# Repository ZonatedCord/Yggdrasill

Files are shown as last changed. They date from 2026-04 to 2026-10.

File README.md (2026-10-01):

<div align="center">

# Yggdrasill

**Smart LED plant pot** — custom ESP32 PCB, addressable LEDs, WLED firmware, a modular 3D-printed vase, and a native iOS app with Apple's Liquid Glass design.






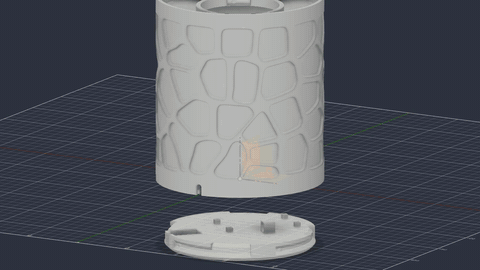
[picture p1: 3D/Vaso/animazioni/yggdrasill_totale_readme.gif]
Full assembly animation


</div>

---

## What it is

A tree-shaped plant pot built from three independent pieces that come together into one object:

<table>
<tr>
<td width="33%" valign="top">

### Hardware
`PCB/`

ESP32 board driving WS2812B / SK6812 addressable LEDs. 4 variants in KiCad, from a full dev-kit to a bare-chip revision.

</td>
<td width="33%" valign="top">

### 3D print
`3D/`

Modular vase — base, lid, trunk, 3 branches, leaves — joined with bayonet/snap-fit joints. FDM-printable in PETG or PLA.

</td>
<td width="33%" valign="top">

### iOS app
`WLED-iOS/`

Liquid Glass redesign (iOS 26) of a WLED controller. mDNS discovery, WebSocket control.

</td>
</tr>
</table>

---

## Assembly preview

<table>
<tr>
<td align="center" width="50%"><b>Leaf insertion</b></td>
<td align="center" width="50%"><b>Branch assembly</b></td>
</tr>
<tr>
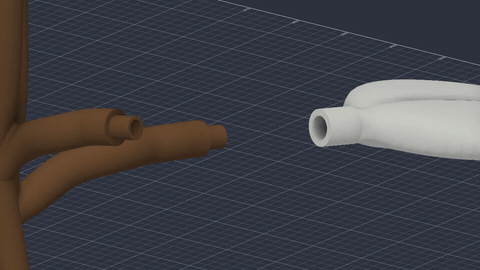
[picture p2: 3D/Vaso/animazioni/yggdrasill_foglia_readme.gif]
<td></td>
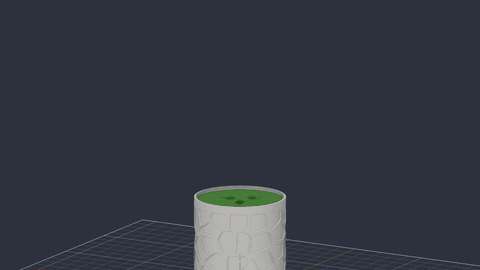
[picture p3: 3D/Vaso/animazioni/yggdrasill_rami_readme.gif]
<td></td>
</tr>
</table>

---

## Status

| Component | Status |
|---|---|
| BaseChipOnly PCB | **Recommended.** Rev 1.03 (`PCB/BaseChipOnly/`, fabricated) works with workarounds. **Rev 2.0** (`PCB/BaseChipOnly_rev2/`) fixes every bring-up defect, new layout — verified by DRC/ERC and simulation only, **not yet fabricated or tested on hardware** |
| BaseDevKit PCB | Active |
| BaseUSB-C rev0.1 PCB | Early revision |
| Foglia PCB | Active |
| Modular vase (`3D/STL_stampa/`) | Redesigned as modular parts — fit clearances and bayonet joints not yet verified by a physical print |
| iOS app (Liquid Glass) | In development |

---

## Quick start

### Hardware

Gerber files are in `PCB/<variant>/Esportazione/`. Upload to JLCPCB or PCBWay.
Open the KiCad project in **KiCad 8+** for schematic / PCB editing.
See [docs/hardware.md](docs/hardware.md) for the full variant table and BOM.

### 3D printing

Print-ready STLs are in `3D/STL_stampa/`. PETG recommended, 0.2 mm layers.
See [docs/3d-printing.md](docs/3d-printing.md) for orientation and joint-clearance notes.

### iOS app

Requires **Xcode 16+** and an **iOS 26+** device or simulator.

```bash
git clone --recurse-submodules https://github.com/ZonatedCord/Yggdrasill
open WLED-iOS/wled.xcodeproj
```

> `WLED-iOS/` is a git submodule pointing to the `liquid-glass-redesign` branch of [ZonatedCord/WLED-iOS](https://github.com/ZonatedCord/WLED-iOS) — a fork of [Moustachauve/WLED-iOS](https://github.com/Moustachauve/WLED-iOS) restyled with Apple's Liquid Glass (iOS 26). Already cloned without `--recurse-submodules`? Run `git submodule update --init`.

---

## Repository structure

```
Yggdrasill/
├── PCB/               KiCad projects — 4 board variants + footprint library
├── 3D/                Modular vase — Vaso/ (Fusion source + STEP + animations), STL_stampa/ (print-ready STLs)
├── WLED-iOS/          iOS app (Liquid Glass, GPL v3) — git submodule → ZonatedCord/WLED-iOS @ liquid-glass-redesign
├── docs/              Hardware, iOS, 3D, and assembly documentation
│   └── hardware-reviews/  PCB analysis notes
├── LICENSE            CC BY-NC-SA 4.0 (hardware + 3D)
├── LICENSE-NOTICES.md Dual-license clarification
├── CHANGELOG.md
└── CONTRIBUTING.md
```

---

## Documentation

- [Hardware variants & BOM](docs/hardware.md)
- [iOS app architecture & Liquid Glass](docs/ios-app.md)
- [3D printing guide](docs/3d-printing.md)
- [Assembly guide](docs/assembly.md)
- [BaseChipOnly — how the board works](docs/base-chiponly-pcb.md) · [Rev 2.0: tests and changes](PCB/BaseChipOnly_rev2/README.md)
- [BaseChipOnly hardware review](docs/hardware-reviews/base-chiponly-review.md) · [bring-up defects & fixes](docs/hardware-reviews/base-chiponly-fixes.md)

---

## License

**Hardware & 3D models** (`PCB/`, `3D/`, `docs/`) — Creative Commons Attribution-NonCommercial-ShareAlike 4.0 International, Copyright (c) 2025 Marco Barlera. Free for personal and maker use; commercial use requires explicit written permission.
See [LICENSE](LICENSE) · [creativecommons.org/licenses/by-nc-sa/4.0](https://creativecommons.org/licenses/by-nc-sa/4.0/)

**iOS app** (`WLED-iOS/`) — GNU General Public License v3.0, inherited from [Moustachauve/WLED-iOS](https://github.com/Moustachauve/WLED-iOS). Copyleft; cannot be changed.
See [WLED-iOS/LICENSE](WLED-iOS/LICENSE)

Full dual-license details: [LICENSE-NOTICES.md](LICENSE-NOTICES.md)

---

<div align="center">

**Marco Barlera** — [marcobarlera.com](https://marcobarlera.com) — barleramarco05@gmail.com

Commercial licensing inquiries: contact via email.

</div>

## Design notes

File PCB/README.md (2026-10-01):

# PCB — Hardware Variants

KiCad 8 projects. ESP32 + WS2812B/SK6812 addressable LEDs.

| Folder | Description | Status | Gerbers |
|---|---|---|---|
| `BaseDevKit/` | ESP32 dev kit carrier | Active | `BaseDevKit/Esportazione/` |
| `BaseChipOnly/` | Bare ESP32-WROOM-32, compact — rev 1.03 as fabricated | Superseded by the next rev | `BaseChipOnly/Esportazione/` |
| `BaseChipOnly_rev2/` | BaseChipOnly HW Rev 2.0: all bring-up fixes + new layout (see its `README.md`) | Verified on paper (DRC/ERC/simulation), not yet fabricated | `BaseChipOnly_rev2/Esportazione-2026-09-30/` |
| `BaseUSB-C_rev0.1/` | USB-C power input | Early rev | — |
| `Foglia/` | Leaf-shaped decorative board | Active | `Foglia/Esportazione/` |
| `Impronte/` | Custom KiCad footprint library | Library | — |

For fabrication details and BOM see [docs/hardware.md](../docs/hardware.md).

How BaseChipOnly works: [docs/base-chiponly-pcb.md](../docs/base-chiponly-pcb.md). For the design review see [docs/hardware-reviews/base-chiponly-review.md](../docs/hardware-reviews/base-chiponly-review.md).

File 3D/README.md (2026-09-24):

# 3D Models

FDM-printable parts for the Yggdrasill LED plant pot. The vase is now a **modular design** (base + lid + trunk/vase + 3 branches + leaves) with bayonet/snap-fit joints, replacing the earlier single-piece `VasoGiusto` body.

## Folder layout

- `3D/Vaso/` — Fusion 360 source of truth: STEP files (`Base.step`, `Coperchio.step`, `Vaso.step`, `Vaso_senza_texture.step`), the raw CAD-orientation STL exports, and `animazioni/` (assembly animation renders).
- `3D/STL_stampa/` — **print-ready** STLs, reoriented/optimized per part for the slicer. Use these for printing.

## Parts (`3D/STL_stampa/`)

| File | Description | Bed footprint (X×Y×Z mm) | Print notes |
|---|---|---|---|
| `Vaso.stl` | Trunk / vase body | 150×150×167 | Print **capovolto** (upside down) — cable slot must be on the print bed |
| `Base.stl` | Vase base — carries the PCB mounting points | 135×135×25 | Bayonet joint to lid — see clearances below. **Designed for `BaseChipOnly` only**, see PCB compatibility below |
| `Coperchio.stl` | Lid | 143×143×18 | Bayonet joint to base — see clearances below |
| `Ramo_1.stl` | Branch 1 | 101×129×324 | Too tall for upright printing on a 256 mm-Z printer (P2S) — must lie down or print at an angle |
| `Ramo_2.stl` | Branch 2 | 157×128×335 | Too tall for upright printing on a 256 mm-Z printer (P2S) — must lie down or print at an angle |
| `Ramo_3.stl` | Branch 3 | 99×153×324 | Too tall for upright printing on a 256 mm-Z printer (P2S) — must lie down or print at an angle |
| `Foglia.stl` | Decorative leaf, pairs with `PCB/Foglia/` | 83×27×135 | Some already printed — need **9 total** |

### Important print details

- **Rough/textured skin** on the branches applies **only** to the branch bodies — it must be **excluded** from the tenons ("codoli") and the square mounting boss ("cubotto"), or the joints won't fit.
- Fit clearances are simulated but **not yet verified empirically**: 0.2 mm/side on the bosses, 0.225 mm on the base. **Print small bayonet test rings for base + lid first**, before committing filament to the full-size parts — the snap-fit has only been checked in simulation.
- If a branch doesn't fit the print bed/angle in your slicer, a hidden joint/graft can be added to shorten it for printing in two pieces — re-export from Fusion if so.

## PCB compatibility

These files (`Base.stl`'s PCB mounting points, and `TasselloFissaggioPCB.stl`) are designed for the **`BaseChipOnly`** PCB variant only (see [PCB/BaseChipOnly](../PCB/BaseChipOnly)). Using `BaseDevKit` or `BaseUSB-C` instead requires redesigning the base's mounting points in Fusion to match that board's outline/holes before printing.

## Assembly animations

Lightweight renders for the README live in `3D/Vaso/animazioni/`:
- `yggdrasill_foglia_readme.gif` — leaf insertion
- `yggdrasill_rami_readme.gif` — branch assembly
- `yggdrasill_totale_readme.gif` — full assembly

Full-quality versions (`*.mp4`/non-`_readme` `.gif`) are also kept in the same folder for reference/editing.

For print settings and assembly notes see [docs/3d-printing.md](../docs/3d-printing.md).

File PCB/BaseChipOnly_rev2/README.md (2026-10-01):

# BaseChipOnly — HW Rev 2.0

Base board of the Yggdrasill lamp: ESP32-WROOM-32U running WLED, 5 V input, drives the 9 leaf boards (`../Foglia`, 15 WS2812B each, wired in parallel). This is the second revision of `../BaseChipOnly` (rev 1.03, the board that was actually fabricated and brought up).

How the board works, power budget and WLED settings: [`docs/base-chiponly-pcb.md`](../../docs/base-chiponly-pcb.md).

> ## ⚠️ Limitation: verified on paper, not on a real board
>
> Rev 2.0 has **not been fabricated or assembled yet**. Everything below was checked with design-rule tools, file cross-checks and circuit simulation — nothing has been measured on hardware. Simulations use component models (TI's LM2596 model, generic MMBT3904/SS34/LED models) and assumptions (cable resistance, wire length to the leaves, capacitor derating) that may differ from reality. The firmware/boot of the ESP32 cannot be simulated: "it boots" means EN and IO0 reach the right levels at the right time.
>
> Before trusting it, build one board and follow the **first power-up procedure** in `docs/base-chiponly-pcb.md`, then test the auto-reset with `esptool.py flash_id`.

## Status

| | |
|---|---|
| Schematic | complete, ERC 0 errors |
| PCB | complete, DRC 0 errors, schematic ↔ PCB parity clean |
| Fab files | `Esportazione-2026-09-30/` (Gerbers, drill, BOM with MPNs, pick-and-place, assembly PDF with values, schematic PDF, 3D preview) |
| Fabricated | **no** |
| Tested on hardware | **no** |

## Tests performed (all theoretical)

| Test | Tool | Result |
|---|---|---|
| Electrical rules check | KiCad ERC | 0 errors |
| Design rules check + schematic parity | KiCad DRC `--schematic-parity` | 0 errors, 0 unconnected, 0 parity issues (12 known items: 0.2 mm thermal-via drills of the ESP32 footprint, same as rev 1.03) |
| Copper vs schematic | Gerber X2 pad attributes of the exported front copper | 120 / 120 pads on the right net |
| Pinout of every active part vs datasheet | netlist + datasheets | 0 mismatches (LM2596S-ADJ, USBLC6-2SC6, MMBT3904, diodes, polarised caps, connectors, ESP32) |
| ESP32 strapping pins | netlist review | IO0 pull-up + BOOT; IO2/IO12 floating (download mode OK, 3.3 V flash); IO5/IO15 internal pull-ups |
| Trace current capacity | IPC-2221, 1 oz outer layer, +10 °C | all power traces above their current (e.g. +5V bus 3 mm → 5.3 A for ~3.3 A) |
| Fab limits | JLCPCB rules | tracks ≥ 0.2 mm, vias 0.6/0.3, copper ≥ 1 mm from edge, silkscreen ≥ 0.8 mm / 0.15 mm |
| Mechanical / visual | KiCad 3D render | polarity marks, orientation, ≥ ~1 mm between parts in the regulator block, ≥ 1.1 mm from the ESP32 |
| Auto-reset (both esptool sequences) | ngspice | enters download mode; serial monitor does not reset the board |
| Power-on EN timing | ngspice | EN rises 13.7 ms after 3.3 V (spec ≥ 50 µs) |
| 3.3 V regulator: nominal, LEDs at 3 A, minimum input, start-up | ngspice + Texas Instruments LM2596 model (SNVMA65, credited in `LICENSE-NOTICES.md`) | 3.28 V, ≥ 3.21 V worst case; needs ≥ ~4.5 V at its input |
| Status LED current | ngspice | 4.6–6.7 mA |
| LED data line to 9 parallel leaves | ngspice | clean ~370/770 ns pulses with R5 = 100 Ω |

Re-run the checks with `./verifica.sh` (ERC + DRC/parity + fab export + Gerber cross-check). Simulations: `simulazioni/README.md` (run `simulazioni/models/get_lm2596_model.sh` once to fetch the TI model).

## Changes from rev 1.03

**Bugs fixed (all seen during the rev 1.03 bring-up)**

| Rev 1.03 | Rev 2.0 |
|---|---|
| D2 (SS34 catch diode) reversed — shorts the regulator switch node | correct polarity, silkscreen matches |
| D1 (status LED) reversed | correct polarity; GND via moved out of the pad (likely cause of the dark LED) |
| Auto-reset wired wrong: both emitters to GND — idle adapter held the ESP32 in reset, esptool could never enter download mode | standard cross-coupled DTR/RTS circuit, like ESP32 DevKit boards |
| No BOOT / RESET buttons | SW1 BOOT, SW2 RESET (C&K PTS810), centred on the top edge |
| L1 1008 inductor, no value — burned out | Bourns SRN6045TA-101M, 100 µH, Isat 1.33 A |
| Polyfuse 12 A in 0603 — protects nothing | Bourns MF-LSMF400/12X, 4 A hold, 2920 |
| U3 (USBLC6) GND pin unconnected — no ESD protection | GND connected, VBUS to +5V (ST reference circuit) |
| TVS: bidirectional symbol, SMF5.0A part on an SMA footprint | SMAJ5.0A, unidirectional, matches the footprint |
| Reference and Value swapped on the PCB, footprints not linked to the schematic | fixed: correct BOM / pick-and-place, Update-PCB-from-Schematic works |
| 12 ESP32 thermal vias with no net | tied to GND |
| Silkscreen typo "GDN" | "GND" |

**Improvements**

- COUT2 220 µF tantalum (Kyocera AVX TPSC227M006R0100) next to the 47 µF MLCC, for LM2596 loop stability.
- C4 100 nF → 1 µF (EN delay, Espressif guideline) — from the simulations.
- R5 470 Ω → 100 Ω (clean data pulses to the 9 parallel leaves) — from the simulations.
- Auto-reset transistors specified as MMBT3904 (no part number before).
- +3V3 traces 0.2 → 0.5–1.0 mm; SW node 1.2–1.5 mm.
- New layout: functional blocks, regulator with a short switching loop and room for hand soldering, solid GND plane on the back, no via-in-pad on GND, silkscreen to fab minimums, HW Rev 2.0 printed on the board.

**Unchanged on purpose:** board outline and mounting holes (the printed base and `TasselloFissaggioPCB.stl` still fit), J1 barrel jack, J2 terminal, J3 programming header (external USB-UART adapter, no USB-C), ESP32 position, C1, LED data on GPIO13.

## Known limits

- The LM2596 needs ≥ ~4.5 V at its input at 500 mA: use a good 5 V 4 A PSU with a short, thick cable and keep the WLED current limiter at 3000 mA.
- The USB-UART adapter must break out **DTR and RTS** at 3.3 V for the auto-reset; otherwise use BOOT/RESET.
- Button reachability inside the printed base not checked.

## Folder contents

| Path | What |
|---|---|
| `BaseChipOnly.kicad_pro/.kicad_sch/.kicad_pcb` | KiCad 9 project |
| `Esportazione-2026-09-30/` | fabrication files for rev 2.0 |
| `verifica.sh` | all automatic checks in one go |
| `simulazioni/` | ngspice decks, plots, results |
| `FIX_LOG.md` | session-by-session log of every change (Italian) |
| `BaseChipOnly-backups/fixpcb_2026-09-30.py`, `relayout-work/relayout.py`, `build.sh` | scripts that generated the PCB (record of every edit; their input boards live in the local, git-ignored `BaseChipOnly-backups/`) |
| `FileImpronte/` | ESP32-WROOM-32U symbol / footprint / 3D model |

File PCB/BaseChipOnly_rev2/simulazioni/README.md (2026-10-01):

# BaseChipOnly — circuit simulations (2026-09-30)

SPICE simulations of every analog block of the base board, run with **ngspice 47** (`brew install ngspice`) in PSpice-compatibility mode (`.spiceinit`). Component values and nets are taken from `../BaseChipOnly.kicad_sch`.

What a SPICE simulation can and cannot tell you: it checks voltages, currents and timing of the circuit around the ESP32. It does **not** run the ESP32 firmware — "does the chip boot" is answered by checking that EN and IO0 reach the right levels at the right time, which is exactly what the ESP32 needs to boot or enter download mode.

## Results

| # | Block | Result | Verdict |
|---|---|---|---|
| 01 | **Auto-reset** (esptool UnixTight + Classic sequences) | EN pulled to 0.07 V during reset; when EN is released, IO0 is at 0.07 V and stays low for 36–48 ms after EN crosses 2.475 V → **download mode**. Serial monitor opening with DTR=RTS=1 → no reset. | ✅ works |
| 01b | Auto-reset **as fabricated (rev 1.03)** | Idle adapter holds EN at 0.04 V (chip stuck in reset); the esptool sequence never pulls EN low. Explains the bring-up ("disconnect DTR/RTS or it won't work"). | ❌ confirmed broken |
| 01c | Auto-reset with **C4 = 1 µF** | Same as 01, EN crosses the threshold 13.7 ms after release, IO0 still low for another 36 ms. | ✅ works |
| 02 | **LM2596 buck**, nominal 5 V in, ESP32 load 60/250/500 mA | +3V3 = **3.280 V**, ripple 0.8 mV p-p, minimum 3.263 V during 500 mA TX bursts, L1 peak 0.6 A in steady state. | ✅ |
| 02b | Buck, **LEDs drawing 3 A** from +5V (WLED limiter) + real switch saturation + 500 mA TX | +5V sags to 4.51 V (0.15 Ω cable+jack+fuse), +3V3 stays 3.28 V, **minimum 3.21 V** during TX. | ✅ small margin |
| 02c | Buck **minimum input voltage** at 500 mA | Regulates down to **~4.5 V** in; 4.3 V in → 3.11 V out; below ~4.2 V the ESP32 minimum (3.0 V) is lost. | ⚠️ see note |
| 02d | Buck start-up with a real adapter (5 V in 10 ms) | L1 peak **0.86 A** (< Isat 1.33 A), +3V3 in 6.9 ms, overshoot 3.43 V (< 3.6 V max). With a 1 ms edge (hot-plugging into a live PSU) L1 briefly reaches ~3 A, limited by the LM2596 current limit. | ✅ |
| 03 | **Power-on**, EN delay vs +3V3 (C4 100 nF) | EN crosses 2.475 V 1.05 ms after +3V3 is up (adapter unplugged). With the adapter connected and idle, EN is back-fed to 1.7 V before power and rises only **65 µs** after +3V3 (spec ≥ 50 µs). | ⚠️ marginal |
| 03b | Power-on with **C4 = 1 µF** | EN 13.7 ms after +3V3 (3.3 ms with the adapter connected). IO0 high → normal boot. | ✅ |
| 04 | **Status LED** D1 (R0 470 Ω from 5 V) | 6.7 mA (red) / 4.6 mA (white/blue). Not too much current; D1 being dark on the rev 1.03 board is not an electrical-design problem. | ✅ |
| 05 | **LED data line** to 9 leaves in parallel | With R5 = 470 Ω the pulses seen at a leaf (2.5 V threshold) shrink: 0.3 m wires → "0" ≈ 265 ns, "1" ≈ 670 ns; 0.6 m → "0" ≈ 190 ns, "1" ≈ 600 ns (WS2812B limits: T0H ≥ 220 ns, T1H ≥ 580 ns). With **R5 = 100 Ω**: "0" 350–370 ns, "1" 750–770 ns, no ringing. | ⚠️ → fixed with 100 Ω |

## Changes made because of these results

- **C4 100 nF → 1 µF** (EN RC = 10 kΩ + 1 µF, Espressif hardware design guidelines). Removes the 65 µs power-on margin; auto-reset re-verified (01c).
- **R5 470 Ω → 100 Ω** (LED data series resistor). Restores full-width pulses at the leaves.
- **IO0_CTRL1 / EN_CTRL1 = MMBT3904** — the transistors had no part number at all.

Same footprints: only values change, the layout is untouched.

## Note on the LM2596 at 5 V input (02c)

The LM2596 switch is a Darlington with ~1 V saturation, so with 5 V in it needs **≥ ~4.5 V at its VIN pin** to hold 3.3 V at 500 mA. Everything between the PSU and U4 eats into that: PSU tolerance, cable, barrel jack, polyfuse. With the LEDs at 3 A and 0.15 Ω of path resistance it still works (02b), but a long thin cable or a sagging PSU would drop the ESP32 into brown-out. Practical rules:

- use a decent 5 V 4 A supply (a 5.1–5.2 V one is even better) with a short, thick cable;
- keep the WLED current limiter on (3000 mA).

For a future revision, a 1 A LDO (e.g. AP7361C-33, ~0.36 V dropout) would be a better fit than a buck at 5 V → 3.3 V: at ~250 mA average the LDO dissipates < 0.5 W.

## Files

| File | What |
|---|---|
| `01_autoreset.cir`, `01b_…rev103.cir`, `01c_…C4_1u.cir` | auto-reset (new circuit / as fabricated / C4 1 µF) |
| `02_buck_nominal.cir`, `02b_…ledload_vsat.cir`, `02c_…dropout.cir`, `02d_…slowramp.cir` | LM2596 buck (share `buck_common.inc`) |
| `03_poweron.cir`, `03b_poweron_C4_1u.cir` | power-on EN delay (uses `v33.inc` = +3V3 start-up from 02) |
| `04_status_led.cir` | status LED current |
| `05_dataline.cir` | LED data line to 9 leaves |
| `models/get_lm2596_model.sh` | downloads TI's LM2596_3P3 unencrypted transient model (SNVMA65) and derives `models/LM2596_ADJ.lib` (internal divider removed → ADJ version; `LM2596_ADJ_VSAT` adds the datasheet switch saturation). The TI file itself is not stored in the repo |
| `models/transistors.lib` | MMBT3904, SS34, LED models |
| `grafici/*.png` | plots (from `plot.py`) |

## Credits

The LM2596 regulator simulations use Texas Instruments' **LM2596_3P3 Unencrypted PSpice Transient Model** (SNVMA65, © 2015 Texas Instruments Incorporated, [ti.com/product/LM2596](https://www.ti.com/product/LM2596)). The model is not stored in this repository; `models/get_lm2596_model.sh` downloads it from TI and turns it into the adjustable version (internal divider removed, optional switch-saturation drop added). See also `LICENSE-NOTICES.md`.

## Re-run

```sh
cd "PCB/BaseChipOnly_rev2/simulazioni"
models/get_lm2596_model.sh                    # once: downloads TI's model and builds models/LM2596_ADJ.lib
for f in 0*.cir; do ngspice -b "$f"; done     # buck decks take ~4-5 min each
python3 plot.py                               # needs matplotlib + numpy
```

Assumptions worth knowing: COUT1 (47 µF 0805 X5R) derated to 20 µF at 3.3 V bias; 0.15 Ω from PSU to the +5V rail; leaf wires 0.3/0.6 m at ~50 pF/m, WS2812B input ~10 pF; USB-UART adapter outputs 3.3 V with 50 Ω.

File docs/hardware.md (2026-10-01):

# Hardware — PCB Variants

All boards are designed in **KiCad 8**. ESP32 + addressable LEDs (WS2812B / SK6812).

---

## Variants

| Folder | Description | Power | Status | Gerbers |
|---|---|---|---|---|
| `BaseDevKit` | ESP32 dev kit carrier board | 5V barrel/USB | Active | `BaseDevKit/Esportazione/` |
| `BaseChipOnly` | Compact bare ESP32-WROOM-32 | 5V | Rev 1.03 fabricated | `BaseChipOnly/Esportazione/` |
| `BaseChipOnly_rev2` | BaseChipOnly HW Rev 2.0: all fixes + new layout | 5V | Verified on paper only, not yet fabricated | `BaseChipOnly_rev2/Esportazione-2026-09-30/` |
| `BaseUSB-C_rev0.1` | USB-C powered, rev 0.1 | 5V USB-C | Early rev | — |
| `Foglia` | Leaf-shaped decorative board | 5V | Active | `Foglia/Esportazione/` |
| `Impronte` | Custom KiCad footprint library | — | Library | — |

**Recommended for new builds:** `BaseChipOnly` HW Rev 2.0 in `PCB/BaseChipOnly_rev2/` (see its [README](../PCB/BaseChipOnly_rev2/README.md) for the tests done and the not-yet-tested-on-hardware caveat) (all bring-up fixes, BOOT/RESET buttons, working auto-reset). How it works, power budget and WLED settings: [base-chiponly-pcb.md](base-chiponly-pcb.md).

---

## BOM (generic)

| Component | Description | Notes |
|---|---|---|
| ESP32-WROOM-32 | Main microcontroller | WLED firmware |
| WS2812B / SK6812 | Addressable RGB LEDs | SK6812 supports RGBW |
| AMS1117-3.3 or LDO | 3.3V regulator | Per schematic (BaseChipOnly uses an LM2596-ADJ buck) |
| 100nF + 47µF decoupling caps | Power filtering | See schematic |
| USB-C connector | Power input (BaseUSB-C only) | GCT USB4135 or similar |

For detailed BOM per variant, open the KiCad schematic.

---

## Fabrication notes

- **Layer count:** 2 layers
- **Min trace:** 0.2 mm
- **Min drill:** 0.3 mm
- **Surface finish:** HASL or ENIG
- **Thickness:** 1.6 mm

Upload the `Esportazione/` folder contents (or zip) to JLCPCB / PCBWay directly.

---

## Known issues

- `BaseChipOnly` as fabricated: D1 and D2 reversed, auto-reset non-functional, no BOOT/RESET buttons, undersized L1. All fixed in the sources in `PCB/BaseChipOnly_rev2/` (2026-09-30), not yet re-fabricated — see `docs/hardware-reviews/base-chiponly-fixes.md`. The older "via-on-pad short circuit" finding was false; see `docs/hardware-reviews/base-chiponly-review.md`.

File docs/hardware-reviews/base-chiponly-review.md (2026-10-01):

# Design Review — BaseChipOnly

Original review: 2026-03-28 (automated). **Rewritten 2026-09-30** after the bring-up proved its main finding false.

---

## Retraction: the "via-on-pad short circuits" do not exist

The 2026-03-28 version of this document named vias on C2, C3, COUT1, Rbot1 and Rtop1 as the "SHORT-CIRCUIT ROOT CAUSE", claiming each GND via had landed on the supply pad. **That is wrong.** Every one of those vias sits in its pad deliberately and carries the *same* net as the pad, to drop to the B.Cu ground plane.

Disproved two independent ways during the 2026-07/08 bring-up:

- The bare board measures no short between any rail and GND.
- The X2 attributes in the fabricated `F_Cu.gbr` (`%TO.P,comp,pin%` / `%TO.N,net%`) show pad and via on the same net at every flagged location — e.g. `COUT1 pin 2 net=GND`, and the via there is also `GND`.

The false finding came from hand-computing pad positions with the wrong rotation sign, which mirrors every pad about its footprint centre and pairs each via with the opposite pad. The error was self-consistent, which is why it looked convincing. Lesson: never derive pad-to-net mapping from footprint rotation math — read it from Gerber X2 attributes or `kicad-cli`.

The short that actually happened on the first assembled board was a **solder bridge between ESP32 module pins 1 (GND) and 2 (3V3)** — an assembly defect, not a design one. See `base-chiponly-fixes.md`.

---

## Findings that were valid, and their status

All of the following are fixed in the KiCad sources in `PCB/BaseChipOnly_rev2/` (2026-09-30). Full log: `PCB/BaseChipOnly_rev2/FIX_LOG.md`.

| Finding | Status |
|---|---|
| U3 (USBLC6-2SC6) GND pin unconnected | Fixed — pin 2 on GND. VBUS (pin 5) now on +5V as well, so the clamp has its rail reference. |
| Polyfuse 12 A protects nothing | Fixed — 4 A hold / 8 A trip, Bourns MF-LSMF400/12X, 2920, sized for the 9 leaves (135 WS2812B) with a 5 V 4 A PSU and the WLED current limiter at 3000 mA. The old 0603 footprint could not hold any realistic PTC. |
| +3V3 traces 0.2 mm | Fixed — +3V3 tracks widened to 0.5 mm. |
| Reference/Value swapped in the PCB | Fixed — Reference on F.Silkscreen, Value on F.Fab. Footprints are linked to their schematic symbols again, so BOM, pick-and-place and Update-PCB-from-Schematic work. |
| SMF5.0A on a bidirectional TVS symbol | Fixed — replaced with SMAJ5.0A (unidirectional, SMA package). SMF5.0A is an SOD-123F part and never matched the D_SMA footprint anyway. |

The Vout note in the old review used Vref = 1.285 V. The LM2596-ADJ reference is **1.23 V**, so Rtop = 2.0 k / Rbot = 1.2 k gives ≈ 3.28 V. No change needed.

---

## Defects found later (bring-up), also fixed

See `base-chiponly-fixes.md` for evidence. Fixed in the sources on 2026-09-30:

- D2 (SS34 catch diode) reversed
- D1 (status LED) reversed
- Auto-reset transistors wired with both emitters to GND — now the standard cross-coupled DTR/RTS circuit
- No BOOT/RESET buttons — SW1 (BOOT, IO0→GND) and SW2 (RESET, EN→GND) added
- L1 1008 inductor unable to carry the current — now Bourns SRN6045TA-101M (100 µH, Isat 1.33 A)
- COUT1 47 µF MLCC alone on the LM2596 output — COUT2 220 µF tantalum added

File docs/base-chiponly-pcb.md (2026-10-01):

# BaseChipOnly — how the board works

Base board of the Yggdrasill lamp: an ESP32-WROOM-32U running WLED drives the 9 leaf boards (`PCB/Foglia`). This describes **HW Rev 2.0**, sources in `PCB/BaseChipOnly_rev2/` — tests done, changes from rev 1.03 and the *not yet tested on hardware* caveat are in [its README](../PCB/BaseChipOnly_rev2/README.md).

## Block diagram

```
5V PSU ─► J1 barrel jack ─► Polyfuse1 ─► +5V bus ─┬─► J2 terminal (VIN/GND) ─► 9 leaves in parallel
                                                   ├─► C1 1000µF bulk, C2 100nF, D_TVS1 SMAJ5.0A (clamp)
                                                   ├─► R0 + D1  (power-on LED)
                                                   └─► U4 LM2596-ADJ buck ─► L1 100µH ─► +3V3 ─► ESP32 (U1)
ESP32 GPIO13 ─► R5 100Ω ─► U3 USBLC6 (ESD) ─► J2 "Data" ─► DIN of the first WS2812B on every leaf
J3 (GND 3V3 TX0 RX0 DTR RTS) ─► USB-UART adapter; DTR/RTS drive the auto-reset transistors
SW1 BOOT (IO0→GND), SW2 RESET (EN→GND)
```

## Blocks

**Power input.** J1 (GCT DCJ200-10, rated 5 A) → polyfuse → +5V. The +5V rail feeds the LEDs directly; only the ESP32 goes through the buck. D_TVS1 clamps spikes on +5V, C1 buffers the LED current steps.

**3.3 V regulator.** LM2596-ADJ, 150 kHz buck. Vout = 1.23 V × (1 + Rtop1/Rbot1) = 1.23 × (1 + 2.0k/1.2k) ≈ 3.28 V. D2 (SS34) is the catch diode (cathode on SW). L1 Bourns SRN6045TA-101M (Isat 1.33 A). COUT1 47 µF MLCC + COUT2 220 µF tantalum: the tantalum's ESR keeps the LM2596 loop stable. Simulated (TI model): 3.280 V, 0.8 mV ripple, ≥ 3.26 V during 500 mA WiFi bursts. With only 5 V in, the LM2596 runs close to dropout: it needs **≥ ~4.5 V at its input** to hold 3.3 V at 500 mA (its switch drops ~1 V) — see *Known limits*.

**ESP32.** U1 WROOM-32U (external antenna via U.FL). LED data is **GPIO13** = module pin 16 (set 13 in WLED, not 16).

**Programming / auto-reset.** J3 carries TX0/RX0/DTR/RTS. Two NPN transistors in the standard cross-coupled arrangement: DTR=1,RTS=0 → EN low (reset); DTR=0,RTS=1 → IO0 low (bootloader). esptool drives this sequence automatically. R3/R4 pull IO0/EN up; C4 (1 µF, with R4 = the 10 kΩ + 1 µF recommended by Espressif) delays EN at power-on. Verified by simulation for both esptool reset sequences: EN goes to 0.07 V, IO0 is still low when EN comes back up → download mode; opening a serial monitor does not reset the board. BOOT/RESET buttons are the manual fallback (hold BOOT, tap RESET).

**LED data.** R5 (100 Ω) damps ringing on the long wires to the leaves — it was 470 Ω, but with 9 leaves in parallel that RC shrank the WS2812B pulses close to their minimum width (simulated); 100 Ω delivers clean ~370/770 ns pulses; U3 protects the ESP32 pin from ESD coming back up the leaf wiring.

**Status LED.** D1 via R0 470 Ω from +5V → 6.7 mA for a red LED, 4.6 mA for white/blue (simulated). That is **not** too much current (0805 LEDs take 20 mA). D1 stays dark on the first assembled board for a reason still undiagnosed: check that R0 is fitted and reads 470 Ω, then measure the LED-anode pad against GND with the board on (≈5 V = no current; ≈2–3 V = current flowing, LED faulty). On the old layout the LED's GND pad has a via in the middle of the pad that sucks solder into the ground plane — a dry joint there is a likely cause. The new files move every GND via beside its pad.

## The leaves (PCB/Foglia) and the power budget

Each leaf: 15 × WS2812B daisy-chained, 100 nF per LED, 3-pad connector (+5V, Data, GND). The last LED's DOUT is not brought out, so the **9 leaves are wired in parallel** on the same data line: WLED is configured for 15 LEDs and all leaves show the same pattern.

| | |
|---|---|
| LEDs | 9 × 15 = 135 WS2812B |
| Worst case (full white, ~55 mA/LED) | ≈ 7.4 A |
| ESP32 (from +5V, via the buck) | ≈ 0.3 A peak |
| Barrel jack limit | 5 A |

So full white at full brightness is **not possible** on this hardware — WLED's current limiter must be on:

- **PSU: 5 V 4 A** (20 W) recommended
- **WLED → LED preferences → Automatic Brightness Limiter: max current 3000 mA**, LED current 55 mA (5 V WS2812)
- Polyfuse MF-LSMF400/12X (4 A hold, 8 A trip, 2920) — above the 3 A limiter plus ESP32, below the fault currents

If you use a smaller PSU, lower the WLED limit to about 80 % of its rating.

## Layout (re-done 2026-09-30, spaced out 2026-10-01)

Board outline, the four mounting holes, J1, J2, J3, U1 and C1 are where they always were, so the printed base and the PCB mount (`TasselloFissaggioPCB.stl`) still fit. Everything else was re-placed in functional blocks:

- **Left column — 3.3 V buck.** U4 with its pins pointing up; directly above the pins D2 (catch diode), L1 and the output caps COUT1/COUT2/C3, so the switching loop U4 OUT → D2 → GND is a few millimetres long. Rtop1/Rbot1 sit next to the FB pin. CIN1/C2 are right at the VIN pin. The block keeps ~1 mm between parts so it can be hand-soldered with an iron.
- **Bottom left — input.** Jack → polyfuse (2920) → a 3 mm +5V bus that runs across the board to C1 and up to the regulator, with a 2 mm branch to J2. The TVS sits on the bus next to the polyfuse.
- **Bottom right — power LED** (R0 + D1) next to C1, fed by a thin branch of the +5V bus.
- **Under the ESP32 — auto-reset.** R1–R4, C4, the two transistors, then R5/U3 feeding J2 "Data".
- **Top edge — RESET and BOOT buttons**, centred on the board, with RESET/BOOT printed on either side.
- **Back — solid GND plane.** Only a few short signal jumpers cross it (DTR/RTS lanes from J3, EN and IO0 under the module, IO13). Every GND pad has its via beside the pad, not in it (easier hand soldering, no solder wicking — see the D1 note above).
- The credit text stays on the front, right edge; the logo stays on the back.

Rebuild recipe (deterministic, all routing by hand): `PCB/BaseChipOnly_rev2/BaseChipOnly-backups/relayout-work/relayout.py` + `build.sh`.

## Simulations

Every analog block was simulated in ngspice (TI's LM2596 model, MMBT3904 transistors): auto-reset, power-on EN timing, the 3.3 V buck (nominal, LEDs at 3 A, minimum input voltage, start-up), status LED, LED data line. Results, plots and decks: `PCB/BaseChipOnly_rev2/simulazioni/README.md`. Three values changed because of them: **C4 100 nF → 1 µF**, **R5 470 Ω → 100 Ω**, transistors specified as **MMBT3904**.

## Pre-order checks (2026-09-30)

Run `PCB/BaseChipOnly_rev2/verifica.sh` after any change: ERC, DRC with schematic parity, regenerates the fab files and cross-checks every pad of the exported front-copper Gerber against the schematic. Last run: **PASS** (0 ERC errors, 0 DRC errors, 0 unconnected, 0 parity issues, 120/120 pads match).

Also checked by hand:

- **Pinouts** of every active part against its datasheet: LM2596S-ADJ (1 VIN, 2 OUT, 3 GND, 4 FB, 5 ON/OFF), USBLC6-2SC6, MMBT3904 SOT-23 (1 B, 2 E, 3 C), SS34/SMAJ5.0A/LED (pad 1 = cathode), tantalum and C1 (pad 1 = +), J2/J3 order, ESP32 power/EN/IO0/IO13/UART pins.
- **ESP32 strapping pins:** IO0 pulled up + BOOT button; IO2 and IO12 floating (download mode allowed, flash at 3.3 V); IO5/IO15 floating (internal pull-ups).
- **Trace current (IPC-2221, 1 oz outer, +10 °C):** +5V bus 3.0 mm → 5.3 A; J2 branch and jack input 2.0 mm → 4.0 A; SW node ≥ 1.2 mm → 2.7 A; +3V3 ≥ 0.6 mm → 1.7 A. LED current returns through the solid GND plane.
- **Fab limits (JLCPCB):** min track 0.2 mm, vias 0.6/0.3 mm, copper ≥ 1.07 mm from the edge, silkscreen ≥ 0.8 mm / 0.15 mm line. The 12 ESP32 thermal vias are 0.2 mm (same as the rev 1.03 order).
- **3D view:** diode bands, tantalum +, regulator orientation, button access (`Esportazione-2026-09-30/preview-3d-top.png`).
- **Every part has an MPN** except generic resistors/capacitors (value + size is enough).

Not verifiable from the files: the fit of the new buttons in the printed base (they sit on the top edge next to J3), and the USB-UART adapter (must break out DTR **and** RTS at 3.3 V).

## First power-up (recommended)

1. Before soldering the ESP32 module: fit the power section only (J1, polyfuse, TVS, C1/C2/CIN1, U4, D2, L1, COUT1/COUT2/C3, Rtop1/Rbot1).
2. Measure +5V↔GND and +3V3↔GND with the multimeter: anything under ~100 Ω means a solder bridge.
3. Power it (bench supply limited to ~300 mA if available): +3V3 must read 3.25–3.30 V.
4. Fit the ESP32, the auto-reset parts and the buttons; repeat step 2 on +3V3 (the rev 1.03 short was a bridge between module pins 1 and 2).
5. Connect the adapter (3.3 V, GND/TX/RX/DTR/RTS; leave its 3V3 unconnected), flash WLED; the board should enter download mode by itself.

## Known limits

- The ESP32 drives 3.3 V data into WS2812B powered at 5 V (spec wants ≥3.5 V). It works in practice on this build; if leaves flicker, the fix is a 74AHCT1G125 buffer powered from +5V between GPIO13 and R5.
- **LM2596 input headroom.** The regulator needs ≥ ~4.5 V at its input at 500 mA. With the LEDs at the 3 A limit, the +5V rail sits at ~4.5 V (0.15 Ω of cable + jack + polyfuse) and the 3.3 V rail still holds (≥ 3.21 V) — but a long thin cable or a weak PSU would brown out the ESP32. Use a good 5 V 4 A supply (5.1–5.2 V is better) with a short thick cable, and keep the WLED limiter on. A future revision could use a 1 A LDO (e.g. AP7361C-33) instead of the buck.
- 12 DRC "drill 0.2 mm" items: thermal vias of the ESP32 footprint, same as the board already made.

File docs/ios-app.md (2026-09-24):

# iOS App — WLED Native

A native iPhone/iPad app to discover and control WLED devices on the local network.

---

## Overview

Yggdrasill's iOS app is a fork of [Moustachauve/WLED-iOS](https://github.com/Moustachauve/WLED-iOS) (GPL v3), restyled with **Apple's Liquid Glass** design language (iOS 26). Published fork: [ZonatedCord/WLED-iOS](https://github.com/ZonatedCord/WLED-iOS) (`origin`; `upstream` = Moustachauve/WLED-iOS). Embedded here as a **git submodule** tracking the `liquid-glass-redesign` branch — clone Yggdrasill with `--recurse-submodules` to pull it in.

The app communicates with WLED firmware running on the ESP32 via:
- **WebSocket** — real-time state sync
- **WLED JSON API** — device discovery and control
- **mDNS** — automatic device detection on LAN

---

## Architecture

```
WLED-iOS/
├── wled/
│   ├── Model/          # Data models (Device, LEDState, Palette, …)
│   ├── ViewModel/      # ObservableObjects for SwiftUI bindings
│   ├── View/           # SwiftUI views — Liquid Glass redesign here
│   ├── Service/        # Network layer (WebSocket, HTTP, mDNS)
│   └── WLEDNativeApp.swift   # App entry point
├── Data/               # CoreData schema (wled_native_data.xcdatamodeld)
└── wled.xcodeproj
```

Pattern: **MVVM**. Models in `Model/`, view models in `ViewModel/`, views in `View/`.

---

## Liquid Glass redesign

The fork replaces the original flat UI with Apple's **Liquid Glass** material system (introduced iOS 26):

- Device list cards use `.glassEffect()` with specular highlights
- Controls use glass-backed sliders and toggles
- Color picker adopts radial blur behind glass panels
- Light/dark mode: glass adapts automatically to ambient lightness
- Requires **iOS 26+** deployment target (verify in `Info.plist`)

---

## Build

1. Open `WLED-iOS/wled.xcodeproj` in **Xcode 16+**
2. Set a valid development team in Signing & Capabilities
3. Build to a physical device or simulator (iOS 26+)

---

## Dependencies

No external package managers. Pure Swift / SwiftUI + CoreData.

---

## License

GPL v3 — inherited from upstream. See `WLED-iOS/LICENSE`. Cannot be changed.

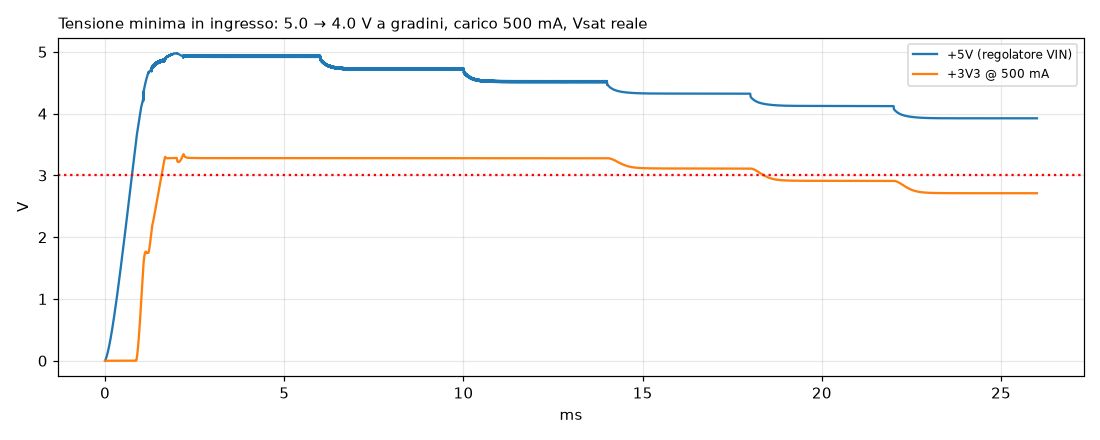
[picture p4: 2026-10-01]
PCB/BaseChipOnly_rev2/simulazioni/grafici/02c_buck_dropout.png

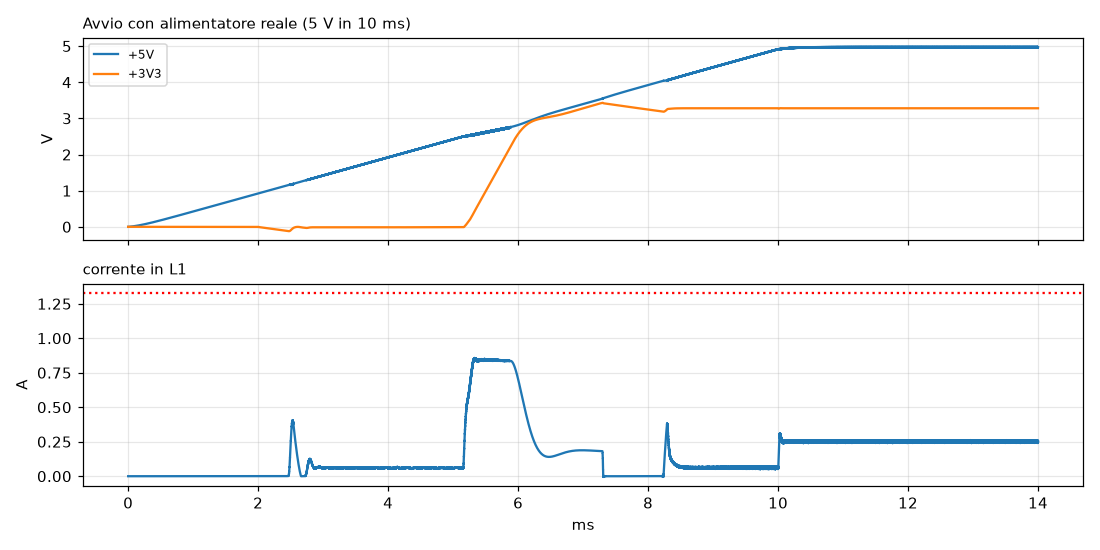
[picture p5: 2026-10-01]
PCB/BaseChipOnly_rev2/simulazioni/grafici/02d_buck_slowramp.png

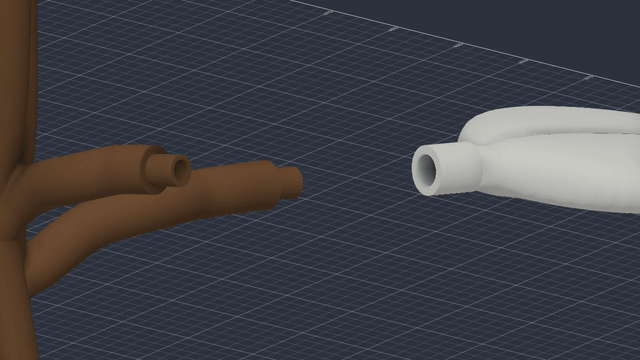
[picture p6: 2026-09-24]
3D/Vaso/animazioni/yggdrasill_foglia.gif

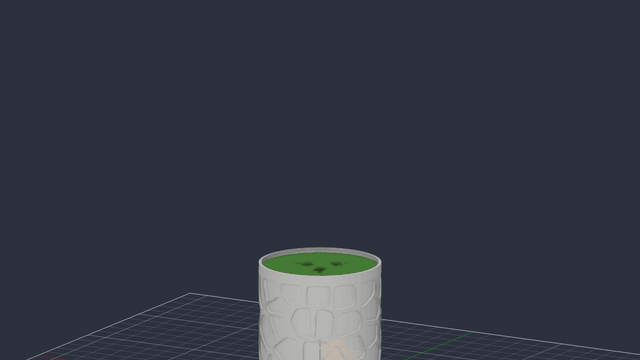
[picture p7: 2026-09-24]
3D/Vaso/animazioni/yggdrasill_rami.gif

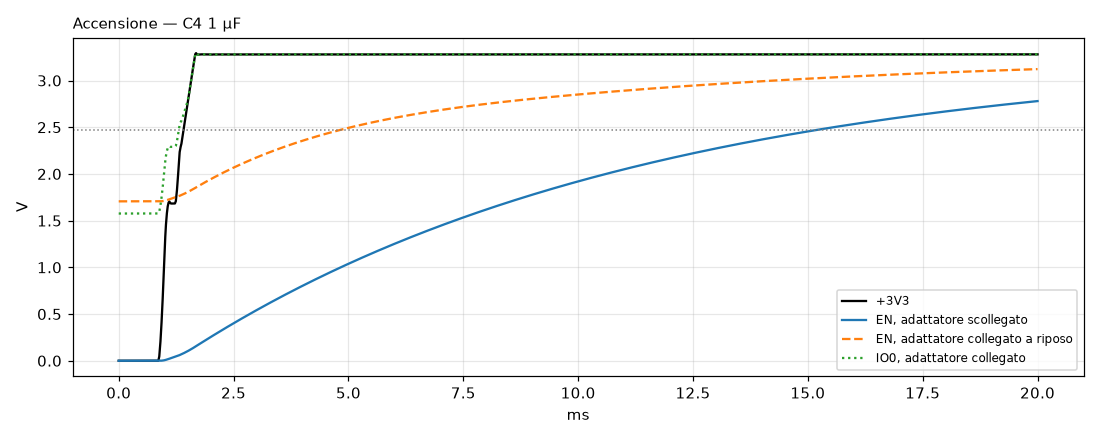
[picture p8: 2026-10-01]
PCB/BaseChipOnly_rev2/simulazioni/grafici/03b_poweron_C4_1u.png

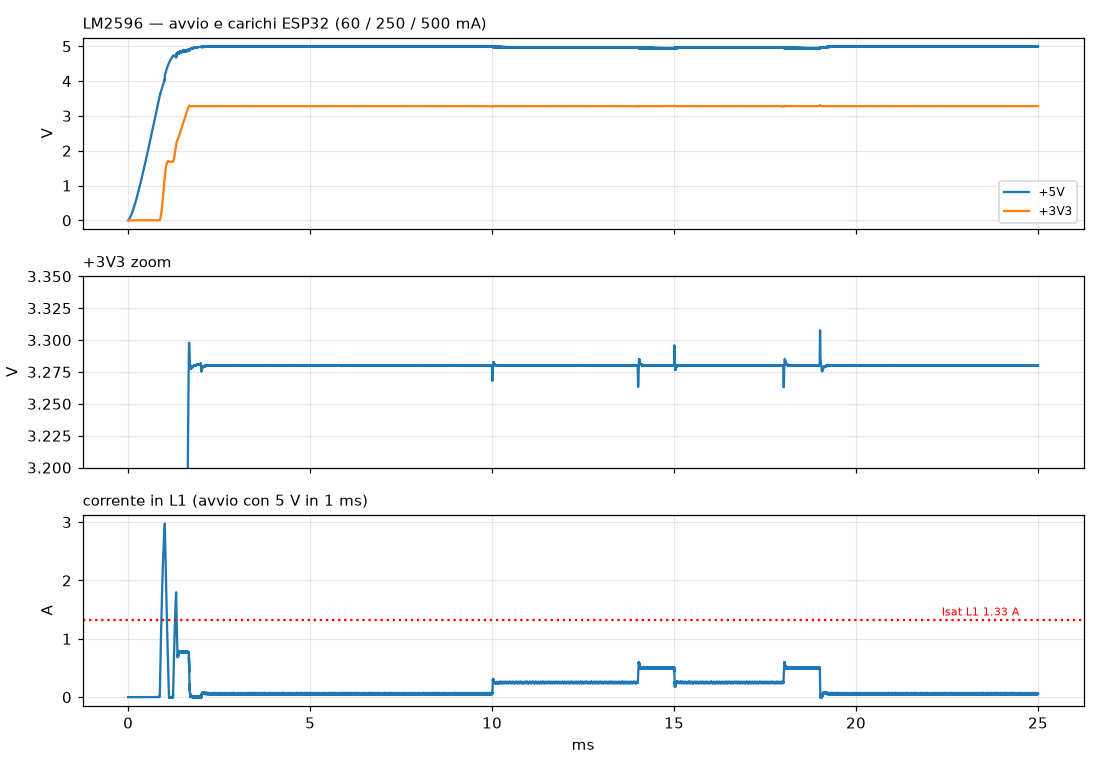
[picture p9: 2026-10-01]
PCB/BaseChipOnly_rev2/simulazioni/grafici/02_buck_nominal.png

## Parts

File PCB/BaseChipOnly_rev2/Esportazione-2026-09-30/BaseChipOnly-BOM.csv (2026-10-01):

Reference | Value | Footprint | MPN | Manufacturer | QUANTITY
C1 | 1000µF | Capacitor_THT:CP_Radial_D10.0mm_P5.00mm |  |  | 1
C2,C3 | 100nF | Capacitor_SMD:C_0805_2012Metric_Pad1.18x1.45mm_HandSolder |  |  | 2
C4 | 1µF | Capacitor_SMD:C_0603_1608Metric_Pad1.08x0.95mm_HandSolder |  |  | 1
CIN1 | 22µF | Capacitor_SMD:C_0805_2012Metric_Pad1.18x1.45mm_HandSolder |  |  | 1
COUT1 | 47µF | Capacitor_SMD:C_0805_2012Metric_Pad1.18x1.45mm_HandSolder |  |  | 1
COUT2 | 220µF 6.3V | Capacitor_Tantalum_SMD:CP_EIA-6032-28_Kemet-C_HandSolder | TPSC227M006R0100 | Kyocera AVX | 1
D1 | LED | LED_SMD:LED_0805_2012Metric_Pad1.15x1.40mm_HandSolder |  |  | 1
D2 | SS34 | Diode_SMD:D_SMA |  |  | 1
D_TVS1 | SMAJ5.0A | Diode_SMD:D_SMA | SMAJ5.0A | Littelfuse (o equivalente) | 1
EN_CTRL1,IO0_CTRL1 | MMBT3904 | Package_TO_SOT_SMD:SOT-23 | MMBT3904 | onsemi / Nexperia (any MMBT3904, SOT-23 B-E-C) | 2
J1 | Barrel_Jack_Connector | USBC:BarrelJack |  |  | 1
J2 | Morsetto | USBC:Morsetto_3_Vie |  |  | 1
J3 | ESP32_PROG_1x6 | Connector_PinHeader_2.54mm:PinHeader_1x06_P2.54mm_Vertical |  |  | 1
L1 | 100µH | Inductor_SMD:L_Bourns_SRN6045TA | SRN6045TA-101M | Bourns | 1
Polyfuse1 | 4A | Fuse:Fuse_2920_7451Metric_Pad2.10x5.45mm_HandSolder | MF-LSMF400/12X | Bourns | 1
R0 | 470Ω | Resistor_SMD:R_0805_2012Metric_Pad1.20x1.40mm_HandSolder |  |  | 1
R1-R4 | 10k | Resistor_SMD:R_0603_1608Metric_Pad0.98x0.95mm_HandSolder |  |  | 4
R5 | 100Ω | Resistor_SMD:R_0805_2012Metric_Pad1.20x1.40mm_HandSolder |  |  | 1
Rbot1 | 1.2k | Resistor_SMD:R_0805_2012Metric_Pad1.20x1.40mm_HandSolder |  |  | 1
Rtop1 | 2.0k | Resistor_SMD:R_0805_2012Metric_Pad1.20x1.40mm_HandSolder |  |  | 1
SW1 | BOOT | Button_Switch_SMD:SW_SPST_PTS810 | PTS810 SJM 250 SMTR LFS | C&K | 1
SW2 | RESET | Button_Switch_SMD:SW_SPST_PTS810 | PTS810 SJM 250 SMTR LFS | C&K | 1
U1 | ESP32-WROOM-32U | USBC:XCVR_ESP32-WROOM-32U |  |  | 1
U3 | USBLC6-2SC6 | Package_TO_SOT_SMD:SOT-23-6_Handsoldering |  |  | 1
U4 | LM2596S-ADJ | Package_TO_SOT_SMD:TO-263-5_TabPin3 |  |  | 1

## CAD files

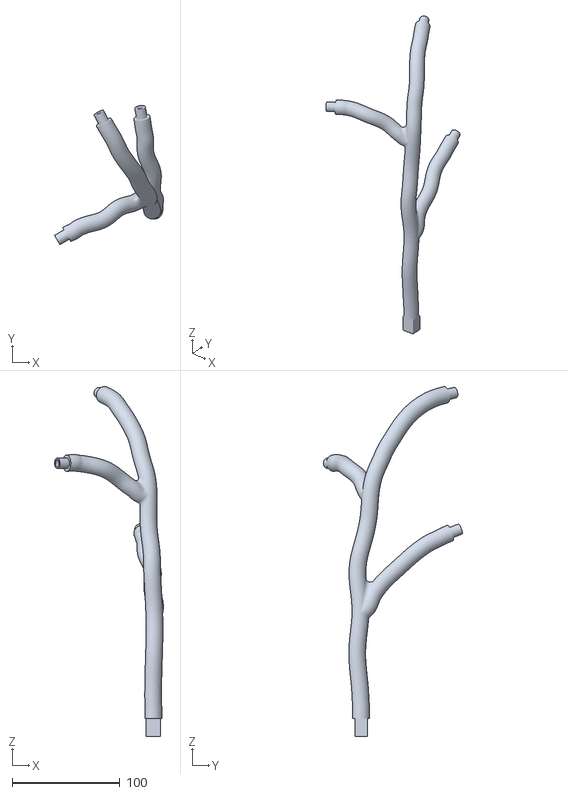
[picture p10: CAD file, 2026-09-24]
3D/STL_stampa/Ramo_1.stl
100.9 x 129.1 x 324.4

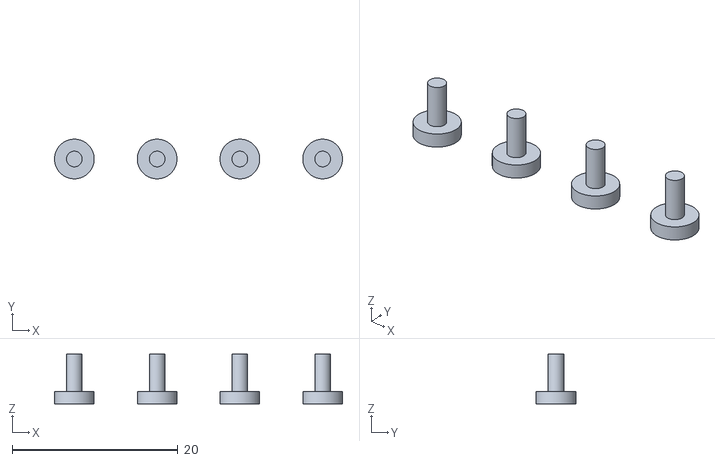
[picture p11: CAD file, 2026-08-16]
3D/TasselloFissaggioPCB.stl
34.8 x 4.80 x 6.00

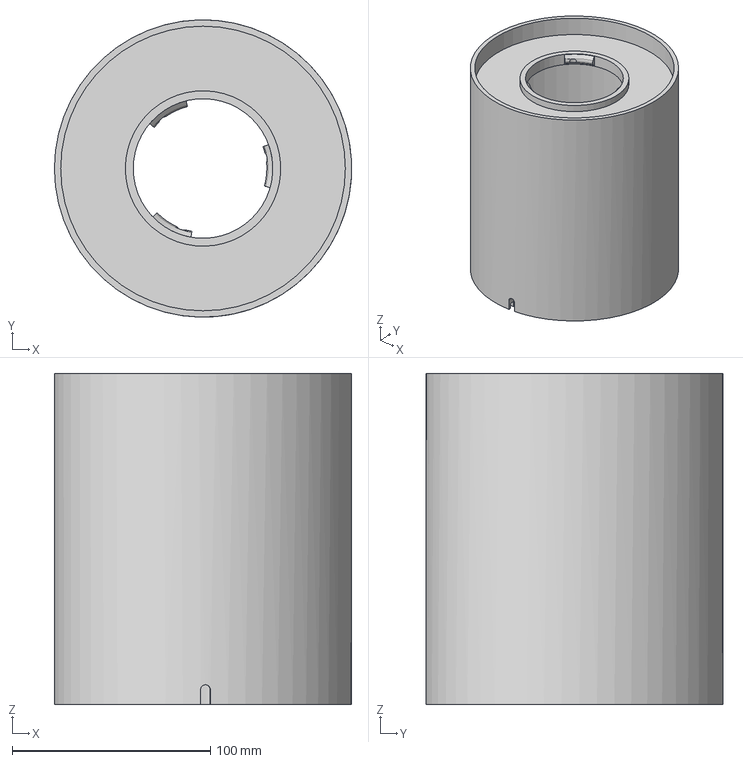
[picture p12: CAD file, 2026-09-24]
3D/Vaso/Vaso_senza_texture.step
150.0 x 150.0 x 167.0 mm

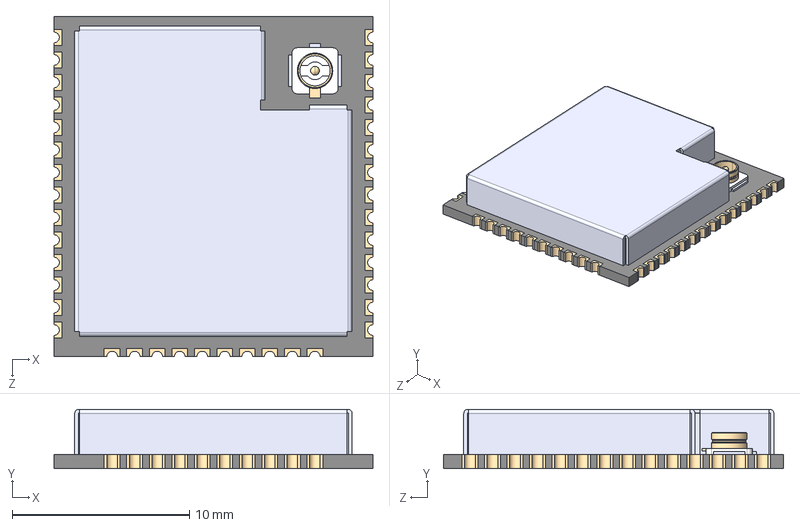
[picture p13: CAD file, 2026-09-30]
PCB/BaseChipOnly_rev2/FileImpronte/ESP32-WROOM-32U-2/ESP32-WROOM-32U.step
18.0 x 3.35 x 19.2 mm

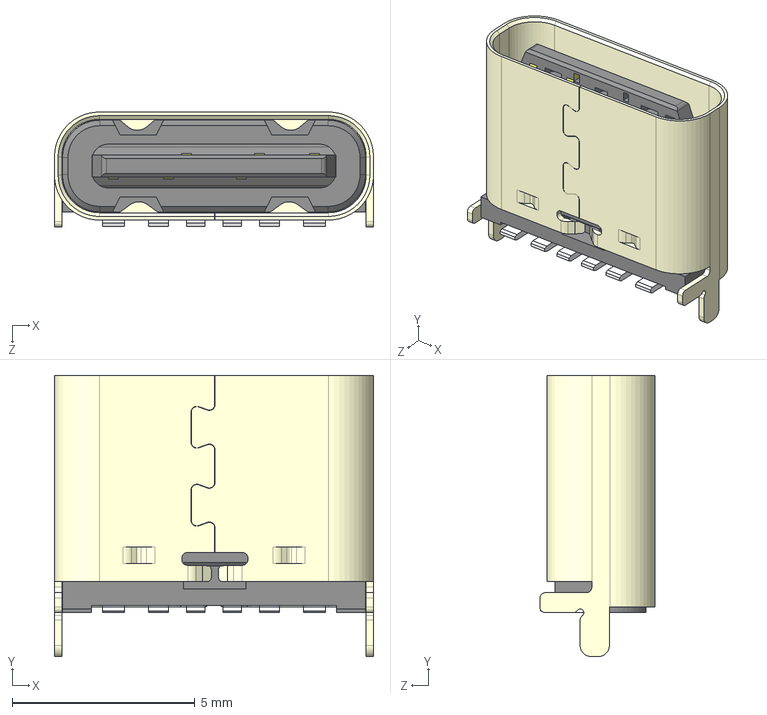
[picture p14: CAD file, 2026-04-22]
PCB/Impronte/usb-c_impronta/UJC-VP-3-SMT-TR.step
8.74 x 7.70 x 3.15 mm

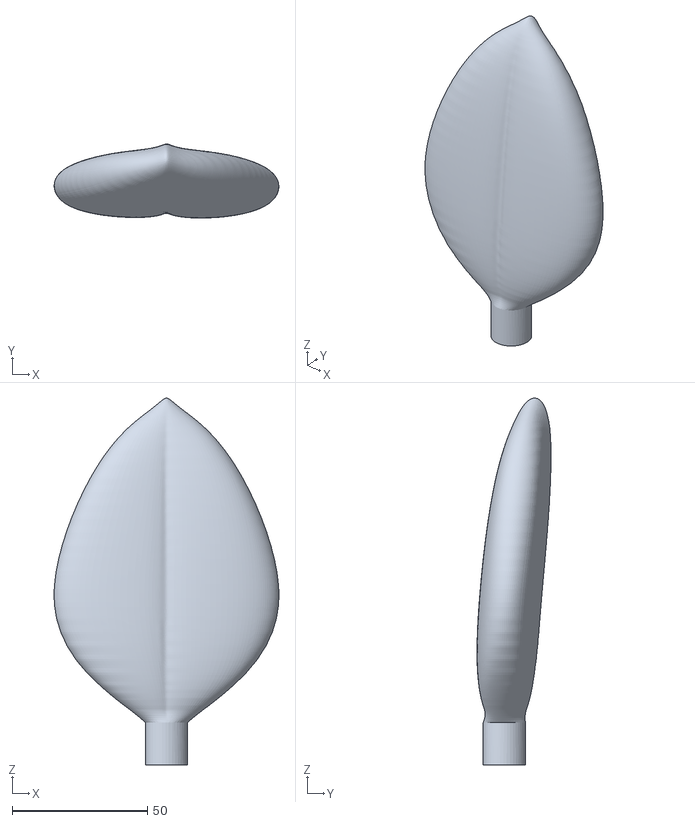
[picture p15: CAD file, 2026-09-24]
3D/STL_stampa/Foglia.stl
82.9 x 27.3 x 135.5

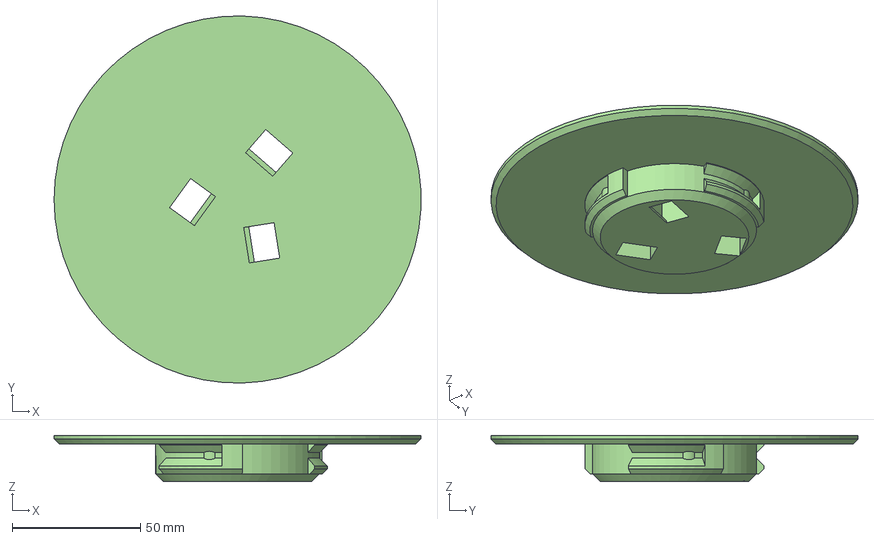
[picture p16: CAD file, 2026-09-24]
3D/Vaso/Coperchio.step
143.1 x 143.1 x 18.0 mm

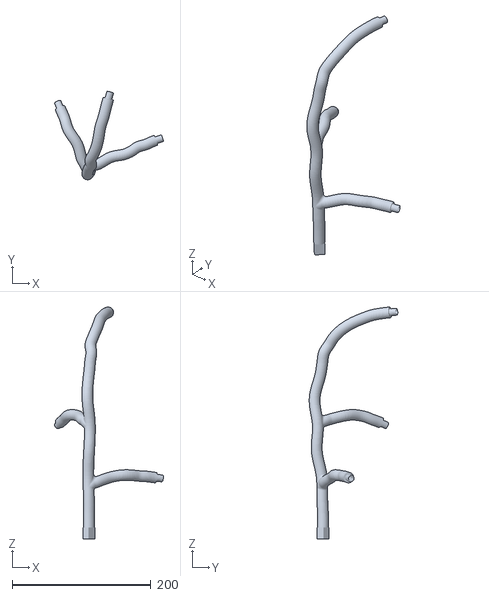
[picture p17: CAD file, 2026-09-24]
3D/STL_stampa/Ramo_2.stl
157.0 x 127.8 x 334.5

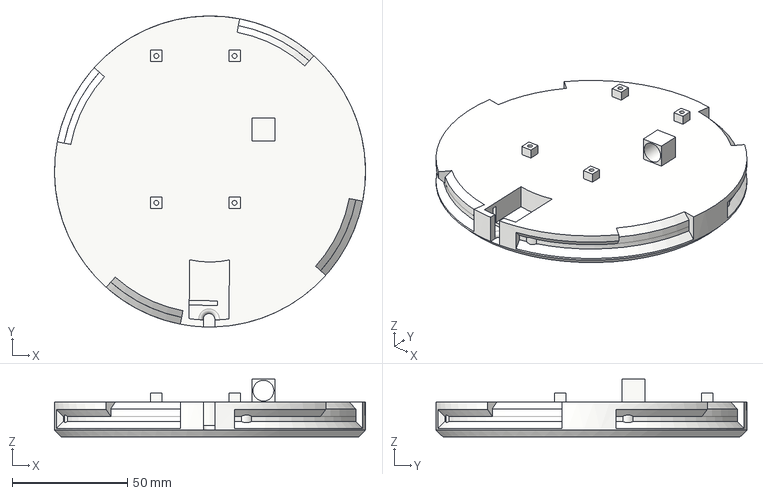
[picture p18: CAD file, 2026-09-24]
3D/Vaso/Base.step
134.6 x 134.6 x 25.0 mm

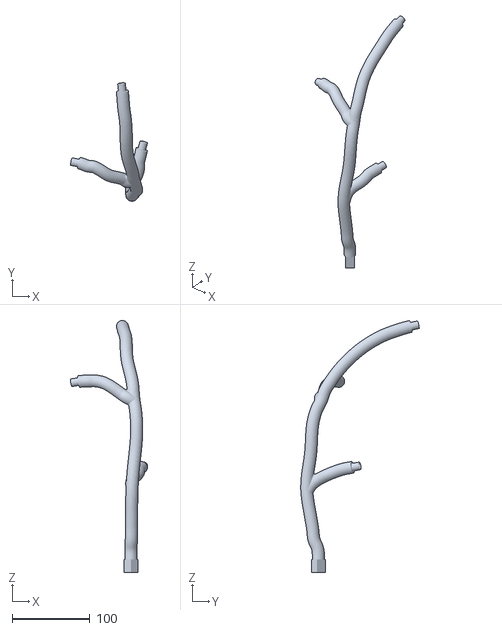
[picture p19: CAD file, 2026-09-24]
3D/STL_stampa/Ramo_3.stl
99.1 x 152.6 x 324.4

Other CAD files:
3D/STL_stampa/Base.stl
3D/STL_stampa/Coperchio.stl
3D/Vaso/Base.stl
3D/Vaso/Coperchio.stl

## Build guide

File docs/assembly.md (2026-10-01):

# Assembly Guide

> Work in progress.

> **PCB compatibility:** the STL files here (base mounting points + `TasselloFissaggioPCB.stl`) are designed for the **`BaseChipOnly`** PCB variant. Other variants (`BaseDevKit`, `BaseUSB-C`) need the base's PCB mounting points redesigned first — see [3d-printing.md](3d-printing.md#pcb-compatibility).

---

## Steps (draft)

1. Print the modular parts from `3D/STL_stampa/`: `Vaso.stl`, `Base.stl`, `Coperchio.stl`, `Ramo_1.stl`, `Ramo_2.stl`, `Ramo_3.stl` — see [3d-printing.md](3d-printing.md) for settings and orientation notes. `Foglia.stl` (×9): some already printed.
2. **Print bayonet test rings for base + lid first** and confirm the snap-fit before committing filament to the full-size `Base.stl`/`Coperchio.stl` — the joint has only been verified in simulation
3. Fabricate PCB — see [hardware.md](hardware.md) for Gerber files and fab notes (`BaseChipOnly` matches the current mounting points as-is)
4. Flash WLED firmware to ESP32 via a USB-UART adapter on J3 (GND, TX0, RX0, DTR, RTS; leave 3V3 unconnected and power from the barrel jack). The next BaseChipOnly rev resets into the bootloader automatically; if not, hold **BOOT**, tap **RESET**, release BOOT. Rev 1.03 boards need the manual procedure in [base-chiponly-fixes.md](hardware-reviews/base-chiponly-fixes.md#flashing-procedure-current-board). In WLED: data pin **GPIO13**, **15 LEDs**
5. Solder LED strip to PCB (DATA, +5V, GND)
6. Route LED strip through the trunk (`Vaso.stl`) internal channels
7. Assemble base → trunk → branches (bayonet joints) → leaves (9×) → lid, per the assembly animations in `3D/Vaso/animazioni/`
8. Mount PCB inside the base (`Base.stl`) with `TasselloFissaggioPCB.stl` — fit against the current `Base.stl` design still unconfirmed by a physical print, see [3d-printing.md](3d-printing.md)
9. Connect power: 5 V, **4 A** recommended — see power requirements below
10. Install iOS app — see [ios-app.md](ios-app.md)
11. App auto-discovers device via mDNS

---

## Power requirements

- Leaves: 9 × `Foglia_Led`, 15 WS2812B each, wired in parallel on the same data line = **135 LEDs**
- Worst case at full white: ~55 mA per LED → **~7.4 A**, more than the barrel jack (5 A) allows
- Recommended PSU: **5 V 4 A** (20 W; 5.1–5.2 V output is even better) on a **short, thick cable**, with WLED → LED Preferences → Automatic Brightness Limiter set to **3000 mA** (LED current 55 mA)
- With a smaller PSU, set the limiter to ~80 % of its rating
- The board's polyfuse (4 A hold) protects against wiring faults, not against running the LEDs without the limiter
- Why the cable matters: the 3.3 V regulator needs ≥ ~4.5 V at its input; at 3 A of LED current every 0.1 Ω of cable costs 0.3 V (simulated, see `PCB/BaseChipOnly_rev2/simulazioni/`)

Details: [base-chiponly-pcb.md](base-chiponly-pcb.md).

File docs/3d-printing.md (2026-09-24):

# 3D Printing Guide

The vase is a **modular design**: base + lid + trunk/vase body + 3 branches + leaves, joined with bayonet/snap-fit joints. Fusion 360 source (STEP) lives in `3D/Vaso/`; print-ready STLs live in `3D/STL_stampa/`.

---

## Files (`3D/STL_stampa/`)

| File | Description | Bed footprint (X×Y×Z mm) | Status |
|---|---|---|---|
| `Vaso.stl` | Trunk / vase body | 150×150×167 | Print capovolto (upside down); cable slot on bed |
| `Base.stl` | Vase base — carries the PCB mounting points | 135×135×25 | Bayonet joint to lid — clearances unverified empirically. **Designed for `BaseChipOnly` only** — see PCB compatibility below |
| `Coperchio.stl` | Lid | 143×143×18 | Bayonet joint to base — clearances unverified empirically |
| `Ramo_1.stl` | Branch 1 | 101×129×324 | Too tall for upright printing on a 256 mm-Z printer (P2S) |
| `Ramo_2.stl` | Branch 2 | 157×128×335 | Too tall for upright printing on a 256 mm-Z printer (P2S) |
| `Ramo_3.stl` | Branch 3 | 99×153×324 | Too tall for upright printing on a 256 mm-Z printer (P2S) |
| `Foglia.stl` | Decorative leaf, pairs with `PCB/Foglia/` | 83×27×135 | Some already printed — need 9 total |

---

## Recommended settings

| Parameter | Value |
|---|---|
| Layer height | 0.2 mm |
| Infill | 20% (gyroid or honeycomb) |
| Material | PETG (preferred) or PLA |
| Supports | Not required for `Vaso`/`Base`/`Coperchio`; branches may need supports depending on chosen orientation |
| Perimeters | 3 |
| Print speed | 50–60 mm/s |
| Skin/texture | Rough/textured skin on branches only — **exclude** it from the tenons ("codoli") and the square mounting boss ("cubotto"), or the joints won't fit |

**PETG preferred** — better heat resistance near LEDs and less brittle than PLA for mechanical fit.

---

## Branches: orientation

`Ramo_1`, `Ramo_2`, and `Ramo_3` (up to 335 mm on their longest axis) exceed the printable Z-height of a 256 mm-build-volume printer (e.g. P2S) if printed upright. They must be printed lying down or at an angle. If a branch still doesn't fit the bed/angle in your slicer, a hidden joint/graft can be added in Fusion to split it into two printable pieces — re-export STLs if this is done.

---

## Bayonet joints: test before committing filament

The base/lid and branch-tenon bayonet/snap-fit joints have only been verified in simulation, not printed. **Print small bayonet test rings for base + lid before printing the full-size parts.** Starting clearances to validate empirically:

- Bosses ("cubotto"): 0.2 mm/side
- Base: 0.225 mm

If a test print doesn't fit, adjust the clearance parameter in Fusion and re-export the affected STL(s).

---

## PCB compatibility

The 3D files in this repo — specifically **`Base.stl`** (which carries the PCB mounting points) and **`TasselloFissaggioPCB.stl`** — are designed to match the **`BaseChipOnly`** PCB variant (see [docs/hardware.md](hardware.md)).

If you're building with a different variant (`BaseDevKit`, `BaseUSB-C`), the board outline and mounting-hole positions differ, so **the base's PCB mounting points need to be redesigned in Fusion** (and `TasselloFissaggioPCB.stl` re-checked/re-exported) before printing — they won't line up as-is.

---

## Assembly notes

The `Foglia` PCB is designed to fit inside / alongside the vase body. The LED strip routes through the internal channels of the trunk (`Vaso.stl`).

The `Foglia.stl` decorative leaf mirrors the `PCB/Foglia/` board shape. Some already printed; 9 total needed.

`TasselloFissaggioPCB.stl` (PCB mounting dowel, `3D/`) mounts the PCB inside the base (`Base.stl`), matching `BaseChipOnly`'s mounting holes. Fit against the current `Base.stl` design is still unconfirmed by a physical print — verify when assembling.

---

## Estimated print time

- **Vaso (trunk):** ~6–9 h (depends on printer speed)
- **Base:** ~1–2 h
- **Coperchio:** ~1 h
- **Ramo (each):** ~4–6 h (depends on orientation/supports)
- **Foglia (each, ×9):** ~1 h

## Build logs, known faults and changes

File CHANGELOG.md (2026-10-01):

# Changelog

All notable changes to Yggdrasill are documented here.
Format: [Keep a Changelog](https://keepachangelog.com/en/1.0.0/).

---

## [Unreleased]

### Added
- Repository structure, docs/, CHANGELOG, CONTRIBUTING, LICENSE-NOTICES
- iOS app Liquid Glass redesign (iOS 26 material system)
- iOS app fork published publicly: [ZonatedCord/WLED-iOS](https://github.com/ZonatedCord/WLED-iOS) (`origin`; `upstream` = Moustachauve/WLED-iOS), embedded as a git submodule tracking the `liquid-glass-redesign` branch
- 3D: vase redesigned as a modular assembly (base + lid + trunk + 3 branches + leaves) with bayonet/snap-fit joints, replacing the single-piece `VasoGiusto` body; Fusion 360 source in `3D/Vaso/`, print-ready STLs in `3D/STL_stampa/`
- 3D: assembly animation renders (leaf insertion, branch assembly, full assembly) in `3D/Vaso/animazioni/`
- Hardware: **BaseChipOnly HW Rev 2.0** in `PCB/BaseChipOnly_rev2/` (verified by ERC/DRC/parity, Gerber cross-check and ngspice simulation; not yet fabricated) — D1/D2 polarity fixed, cross-coupled DTR/RTS auto-reset, BOOT/RESET buttons, L1 SRN6045TA-101M, polyfuse MF-LSMF400/12X (4 A), SMAJ5.0A TVS, 220 µF output cap, USBLC6 GND/VBUS; new tidy layout with solid GND plane; fab files in `Esportazione-2026-09-30/` (not yet fabricated)
- Docs: `docs/base-chiponly-pcb.md` — how the board works, power budget for the 9 leaves, WLED settings
- Hardware: ngspice simulations of every BaseChipOnly analog block (auto-reset, power-on, LM2596 buck incl. worst case and dropout, status LED, LED data line) in `PCB/BaseChipOnly_rev2/simulazioni/`

### Changed
- Docs (`README.md`, `3D/README.md`, `docs/3d-printing.md`, `docs/assembly.md`) updated to reflect the modular vase design
- Docs: power requirements corrected for 135 LEDs (5 V 4 A PSU + WLED limiter 3000 mA, was "5 V 2 A")
- Hardware (BaseChipOnly next rev, from the simulations): C4 100 nF → 1 µF (EN delay per Espressif guidelines), R5 470 Ω → 100 Ω (clean data pulses to 9 parallel leaves), auto-reset transistors specified as MMBT3904
- Hardware (BaseChipOnly Rev 2.0): regulator block spaced out for hand soldering and kept ≥ 1.1 mm from the ESP32, status LED moved next to C1, BOOT/RESET centred on the top edge, silkscreen to fab minimums, `HW Rev 2.0` printed on the board
- Repo: `PCB/BaseChipOnly copia MCP/` renamed to `PCB/BaseChipOnly_rev2/`; TI LM2596 model fetched by script instead of stored

### Fixed
- Docs: retracted the false BaseChipOnly "via-on-pad short circuit" finding (`base-chiponly-review.md`, `hardware.md`, `CONTEXT.md`)

### Removed
- `3D/VasoGiusto.stl`, `3D/BaseVaso.stl`, old `3D/Foglia.stl`/`Foglia.3mf` — superseded by the modular design's `3D/STL_stampa/` parts
- Intermediate animation frame dumps (~400 MB of PNGs) and the earlier "montaggio" animation take, superseded by the current renders in `3D/Vaso/animazioni/`

---

## [0.1.0] - 2026-04-23

### Added
- Hardware: BaseDevKit, BaseChipOnly, BaseUSB-C rev0.1, Foglia PCB variants (KiCad)
- 3D: vase body (VASO_Corpo.stl), cap WIP (VASO-tappo_DaRivedere.stl)
- iOS app: fork of Moustachauve/WLED-iOS with WLED JSON API + WebSocket
- Dual license: CC BY-NC-SA 4.0 (hardware/3D) + GPL v3 (iOS)

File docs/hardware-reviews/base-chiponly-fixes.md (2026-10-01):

# BaseChipOnly — Defects and Fixes

Bring-up session, 2026-07-28 → 2026-08-01. Board reached a working state: 5 V and 3.3 V rails correct, ESP32 boots, WiFi connects, WLED 16.0.1 drives the LED strip.

This file records every defect found, how it was verified, and the proposed fix.

> **Status 2026-09-30:** all defects #1–#10 below are fixed in the KiCad sources in `PCB/BaseChipOnly_rev2/` (schematic and PCB, verified by netlist diff, ERC, DRC with schematic parity, and Gerber X2 attributes). New fabrication outputs are in `PCB/BaseChipOnly_rev2/Esportazione-2026-09-30/`. Not yet fabricated or bench-tested — the auto-reset rework in particular still needs a bench check. Details: `PCB/BaseChipOnly_rev2/FIX_LOG.md`.

> Written in English per the project convention in `CONTEXT.md`.

---

## Verification method

Findings below were confirmed against authoritative sources, not derived by hand:

- **Netlist**: `kicad-cli sch export netlist --format kicadsexpr BaseChipOnly.kicad_sch` — gives `pinfunction` per node
- **Fabricated copper**: X2 attributes (`%TO.P,comp,pin%`, `%TO.N,net%`) in `Esportazione/BaseChipOnly-F_Cu.gbr`
- **Hardware**: multimeter on the assembled board

Hand-computing pad coordinates from `.kicad_pcb` footprint rotation is unreliable — see the correction note at the bottom.

---

## Defects to fix in the KiCad sources

| # | Problem | Evidence | Proposed fix | Severity |
|---|---|---|---|---|
| 1 | **D2 (SS34) reversed.** Catch diode has cathode on GND, anode on /SW. An LM2596 buck needs cathode on SW. As drawn, the diode shorts SW to GND during the switch on-time and provides no freewheel path during off-time. | Netlist: `D2 pin 1 pinfunction "K"` on GND, `pin 2 pinfunction "A"` on /SW | Rotate D2 180°, re-route | **Critical** |
| 2 | **D1 (status LED) reversed.** Anode on GND, cathode through R0 to +5 V. Reverse-biased, never lights. | Netlist: `D1 pin 2 pinfunction "A"` on GND; `Net-(D1-K)` carries `D1 pin 1` + `R0 pin 2` | Rotate D1 180° | Medium |
| 2b | **D1 still does not light after being fitted rotated.** The reversal in #2 is confirmed by the netlist, so it is a real defect — but it is evidently not the only fault on this branch. **Open, not diagnosed.** | Hardware: LED replaced once and later fitted rotated; dark in both cases | See "Open issues" below for the measurement that splits the causes | Medium |
| 3 | **Auto-reset circuit non-functional.** Both transistor emitters go to GND, so esptool cannot drive EN and IO0 in the sequence it expects. Every flash needs a manual jumper. | Netlist: `EN_CTRL1 pin 2 (E)` and `IO0_CTRL1 pin 2 (E)` both on GND. Confirmed on hardware — auto-reset never entered download mode. | Use the cross-coupled circuit: EN transistor base ← DTR, emitter ← RTS; IO0 transistor base ← RTS, emitter ← DTR. Note this **swaps the base assignments** relative to the current design, in addition to lifting the emitters off GND. Derived from esptool's classic reset sequence with FTDI active-low DTR#/RTS# — **bench-verify before committing.** Also add #3b. | **High** |
| 3b | **No BOOT or RESET button.** When auto-reset fails there is no fallback: entering download mode means jumpering module pin 25 to GND by hand while power-cycling. Every error message from flashing tools ("hold the BOOT button…") assumes buttons that don't exist here. | Bring-up experience | Add two tactile switches: **BOOT** (IO0 → GND) and **RESET** (EN → GND), each with the pull-up already present (R3 on IO0, R4 on EN). Cheap, tiny, and independent of whether the auto-reset rework in #3 proves correct — worth having even if #3 works. Keep them reachable once the board is inside the pot. | Medium |
| 4 | **L1 has no value and no MPN**, and the 1008 footprint cannot carry the current. A 1008 inductor is rated well under the LM2596's ~3 A current limit. The fitted part burned out during bring-up. | Schematic value field is just `L`; footprint `Inductor_SMD:L_1008_2520Metric` | ~100 µH, Isat ≥ 1 A, footprint 1210 or 1812. The 3V3 rail feeds only the ESP32 — the LED strip runs off +5 V through J2, so ~500 mA peak is the requirement. | **High** |
| 5 | **Polyfuse is 12 A** — protects neither the LM2596 (3 A max) nor the ESP32. | Schematic value | 1.5 A, after measuring real draw with the intended strip at full brightness | Medium |
| 6 | **U3 (USBLC6-2SC6) GND pin unconnected.** ESD clamping is inoperative. The data signal still passes, because pins 1 and 6 are both `I/O1` and internally the same node. | Netlist: U3 pins 2–5 each on their own unnamed net | Connect the GND pin | Medium |
| 7 | **+3V3 traces too narrow.** | Carried over from the earlier review | Widen | Low |
| 8 | **Reference and Value fields are swapped**, deliberately, so the silkscreen shows component values for hand assembly. Side effect: BOM and pick-and-place exports are wrong, and the board can't be discussed by designator. | Footprint properties | Reference on `F.SilkS`, Value on `F.Fab`, then export an assembly-drawing PDF showing values for hand assembly. Same benefit, no corrupted exports. | Medium |
| 9 | **D_TVS1 uses the bidirectional TVS symbol** (pins A1/A2) but SMF5.0A is a unidirectional part. | Netlist pin functions | Use the unidirectional symbol, or change the part | Low |
| 10 | **COUT1 is a 47 µF ceramic alone** on the LM2596 output. That regulator's compensation expects some ESR; an all-MLCC output is marginal for loop stability. | Design review | Add an electrolytic alongside, or re-check against the LM2596 datasheet's recommended output capacitance | Low |

---

## Bring-up log — what actually failed

**Smoke from L1.** Root cause was a **solder bridge between GND and +3V3 underneath the ESP32 module** (pins 1 and 2 are adjacent). The 3.3 V rail was shorted, the buck drove into that short, and L1 — the only current-limiting element in the path — overheated.

Casualties: L1, and U4 was replaced as a precaution. The ESP32 module survived: the rail was pulled to 0 V, never over-voltage.

Diagnosis path that worked, for next time:

1. Measure +3V3 ↔ GND on the **bare** board first — establishes whether a short is copper or assembly
2. Remove components on the rail one at a time, cumulatively, re-measuring after each. Do not put them back between steps.
3. `< 1 Ω` means a solder bridge or a punctured MLCC; a few ohms means a dead semiconductor

Useful probe points: J3 holes `GND` and `3v3` are plated and on-net even with no header fitted.

---

## Open issues

> Simulation (2026-09-30, `PCB/BaseChipOnly_rev2/simulazioni/04`): R0 470 Ω gives 6.7 mA (red) / 4.6 mA (white) — the current is fine, so the cause is assembly (R0 missing/wrong, dry joint on the via-in-pad GND pad, damaged LED), not the circuit. The auto-reset failure is also reproduced in simulation (`01b`): with the adapter idle, EN is held at 0.04 V.

**D1 status LED is still dark**, even fitted rotated 180° from the silkscreen, and with a replacement LED. The schematic reversal (#2) is confirmed by the netlist and is genuine, but something else on this branch is also wrong. Not yet diagnosed.

Branch under test: `+5V → R0 (470 Ω) → D1 anode … D1 cathode → GND`. For the LED to conduct, the anode must sit on the **left** pad (the R0 side) and the cathode on the **right** pad (GND).

Next measurement — board powered, DC volts, black probe on GND, red probe on the **left** LED pad:

| Reading | Meaning |
|---|---|
| ~5 V | No current flowing. LED still backwards, open, or dead. |
| ~2–3 V | Current *is* flowing and the LED should be glowing. Suspect a dim or faulty LED, or the wrong part fitted. |
| ~0 V | R0 is open or was never populated. Check R0 across its own pads — should read 470 Ω. |

Worth ruling out first: 0805 LED cathode markings are ambiguous between manufacturers (green bar underneath, notch, or a mark on the top face), so "rotated" may not have meant what it looked like. A diode-mode check on the loose LED identifies its anode with certainty before fitting.

Expected current when working: (5 − 2) / 470 ≈ 6.4 mA.

---

## Workarounds for the currently assembled board (rev 1.03)

> The next revision (`PCB/BaseChipOnly_rev2/`) fixes all of these; the notes below apply only to boards made from the rev 1.03 Gerbers.

These apply to the physical board as built, until the sources are fixed:

- **D2**: cathode band on the **lower** pad (the one toward L1), i.e. opposite the silkscreen
- **D1**: cathode mark toward the GND pad — but see "Open issues", this alone did not make it light
- **Flashing**: see below

---

## Flashing procedure (current board)

Auto-reset does not work, and there is no BOOT button. Manual entry into download mode:

1. Close any serial monitor — `pkill -9 screen`. A held port produces `Failed to open serial port`.
2. Wire the USB-UART adapter: `GND`→`GND`, adapter `RXD`→`TX0`, adapter `TXD`→`RX0`. Leave `3v3` disconnected and power the board from the barrel jack — an FT232RL's 3V3OUT supplies only 50 mA, far short of the ESP32's WiFi peaks.
3. **Disconnect DTR and RTS.** If connected, esptool's reset attempt knocks the chip back out of download mode.
4. Jumper **module pin 25 (IO0)** — the bottom-most castellated pad on the module's right edge — to `GND` on J3.
5. Holding the jumper: unplug the barrel jack, plug it back in, wait a second, release the jumper.
6. Flash. https://install.wled.me works; select the `FT232R USB UART` port, `Plain` build.
7. Power-cycle by hand afterwards to run the new firmware.

**WLED configuration**: LED data is **GPIO 13**. Module pin 16 is GPIO13 — do not confuse the module pin number with the GPIO number. Chain: U1 pin 16 (`IO13`) → R5 470 Ω → U3 → J2 pin 1, the terminal silkscreened `Data`.

J2 terminal block: pin 1 `Data`, pin 2 `VIN` (+5 V), pin 3 `GDN` (GND — typo in the silkscreen, worth fixing too).

---

## Correction to the existing review document

`base-chiponly-review.md` names via-on-pad short circuits on C2, C3, COUT1, Rbot1 and Rtop1 as the "SHORT-CIRCUIT ROOT CAUSE". **Those shorts do not exist.** Those vias sit inside the pads deliberately, on the *same* net, to reach the ground plane.

Disproved two ways:

- The bare board measures no short between any rail and GND
- X2 attributes in the fabricated `F_Cu.gbr` show pad and via carrying the same net at every flagged location — e.g. `COUT1 pin 2 net=GND` with the via at that position also `net=GND`

The false finding came from computing pad positions with the wrong rotation sign, which mirrors every pad about its footprint centre and pairs each via with the opposite pad. The error is self-consistent and survives cross-checks against the schematic, which is why it looked convincing.

Two consequences:

- `base-chiponly-review.md` needs rewriting
- `CONTEXT.md` states the issue was "fixed in HW rev 1.03+", which rests on the same false premise and should be removed

Still valid from that document: the oversized polyfuse, the unconnected U3 GND pin, the narrow +3V3 traces, and the bidirectional TVS symbol.

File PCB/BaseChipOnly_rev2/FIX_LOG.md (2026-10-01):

# BaseChipOnly — Log fix pre-fab

## ✅ 2026-10-01 — cartella rinominata in `BaseChipOnly_rev2`, HW Rev 2.0

Cartella `BaseChipOnly copia MCP` → `BaseChipOnly_rev2`. Serigrafia "HW Rev 1.03" → "HW Rev 2.0". Nuovo `README.md` con limiti (verifica solo teorica), test fatti e modifiche rispetto alla rev 1.03. Il modello TI dell'LM2596 non è più nel repo: lo scarica `simulazioni/models/get_lm2596_model.sh`. `verifica.sh`: PASS.

## ✅ Sessione 2026-10-01 — layout più arioso per la saldatura a mano

Su richiesta: la zona sotto J3 e sopra l'LM2596 (L1, D2, condensatori, partitore FB) era troppo fitta per il saldatore. LED di stato (R0 + D1) spostato in basso a destra accanto a C1, TVS spostato a sinistra vicino al polyfuse, LM2596 abbassato di 2,5 mm: ora tra i componenti del blocco regolatore c'è ~1 mm. Pulsanti RESET/BOOT centrati sul bordo alto, scritte simmetriche. Poi (stessa sessione) L1/COUT2 erano a ridosso dell'ESP32: L1 ruotato di 90° (SW in basso verso D2, +3V3 in alto verso i condensatori), D2/partitore FB spostati 0,5 mm a sinistra, COUT1/COUT2/L1 verso sinistra → distanza dall'ingombro ESP32: L1 1,21 mm, COUT2 1,13 mm, COUT1 2,18 mm. Header J3 invariato (niente USB-C, scelta dell'utente). `verifica.sh`: **PASS**. Layout precedente salvato in `BaseChipOnly-backups/BaseChipOnly-layout-v1.kicad_pcb`.

## ✅ Sessione 2026-09-30 (quarta parte) — controlli pre-ordine

Nuovo script `verifica.sh` (ERC + DRC con parità + rigenera Esportazione + confronto pad Gerber/schematico): **PASS**. Controlli a mano: piedinature di tutti i componenti attivi vs datasheet (0 differenze), pin di strapping ESP32, portata in corrente delle piste (IPC-2221), limiti di produzione JLCPCB, vista 3D, polarità. Correzioni: serigrafia portata ai minimi JLCPCB (0,8 mm / tratto 0,15 mm; le scritte di J3 erano 0,5 mm e ora sono centrate sui pin), etichetta Rbot1 spostata, MPN COUT2 = **Kyocera AVX TPSC227M006R0100** (ESR 100 mΩ). Procedura di prima accensione in `docs/base-chiponly-pcb.md`.

## ✅ Sessione 2026-09-30 (terza parte) — simulazioni SPICE di tutta la scheda

Tutto in `simulazioni/` (vedi `simulazioni/README.md` per tabella risultati, grafici e come rilanciarle). ngspice 47 + modello TI dell'LM2596 (SNVMA65, adattato alla versione ADJ).

| Blocco | Risultato |
|---|---|
| Auto-reset (sequenze esptool UnixTight e Classic) | ✅ EN a 0.07 V in reset, IO0 ancora basso quando EN risale → modalità download. Monitor seriale aperto → nessun reset. |
| Auto-reset rev 1.03 (come prodotta) | ❌ adattatore a riposo tiene EN a 0.04 V → chip bloccato in reset. Conferma quanto visto al bring-up. |
| Accensione (EN vs +3V3) | ⚠️ con C4 100 nF e adattatore collegato EN sale solo 65 µs dopo i 3,3 V (spec ≥ 50 µs) → **C4 portato a 1 µF**: 13,7 ms, auto-reset ancora OK. |
| Regolatore LM2596 | ✅ 3,280 V, ripple 0,8 mV, ≥ 3,26 V con picchi WiFi 500 mA; L1 max 0,86 A all'avvio con alimentatore reale. |
| Regolatore con LED a 3 A | ✅ +5V a 4,51 V, +3V3 ≥ 3,21 V. Margine ridotto. |
| Tensione minima in ingresso | ⚠️ servono ≥ ~4,5 V all'ingresso del regolatore a 500 mA (caduta interna ~1 V). → alimentatore buono e cavo corto/spesso; per una revisione futura valutare un LDO da 1 A. |
| LED di stato | ✅ 6,7 mA (rosso) / 4,6 mA (bianco): non è troppa corrente. |
| Linea dati alle 9 foglie | ⚠️ con R5 470 Ω gli impulsi arrivano accorciati vicino al minimo WS2812B → **R5 portato a 100 Ω**: impulsi puliti ~370/770 ns. |

Modifiche conseguenti (solo valori, stesse impronte, layout invariato): **C4 1 µF**, **R5 100 Ω**, transistor **MMBT3904** (prima senza codice). Verificato dopo: ERC 0 errori, DRC con parità pulito, netlist identica nei collegamenti. `Esportazione-2026-09-30/` rigenerata.

## ✅ Sessione 2026-09-30 (seconda parte) — layout rifatto, polyfuse 4 A, foglie analizzate

**Il PCB del progetto è ora il nuovo layout ordinato.** Verifiche sul file del progetto:
- DRC con parità schematico: **0 errori elettrici, 0 non connessi, 0 differenze di parità** (restano i 12 fori 0.2 mm dei via termici ESP32, uguali alla scheda già prodotta, e 6 avvisi solo estetici di serigrafia: logo retro + etichetta COUT1).
- Gerber X2 del nuovo `F_Cu`: **120 pad controllati contro lo schematico, 0 differenze.**
- File di produzione rigenerati in `Esportazione-2026-09-30/` (+ anteprime `preview-front-copper.png` / `preview-back-copper.png`).

Cosa è cambiato:
- Foglie (`PCB/Foglia`, solo analizzate): 15 WS2812B ciascuna, 9 in parallelo = 135 LED, fino a ~7.4 A a bianco pieno → alimentatore 5 V 4 A + limitatore WLED a 3000 mA. Spiegazione completa: `docs/base-chiponly-pcb.md`.
- Polyfuse → **MF-LSMF400/12X** (4 A hold / 8 A trip, 12 V, 2920), schematico e PCB.
- Layout a blocchi: regolatore con pin in alto e anello di commutazione cortissimo, ingresso/protezioni in basso a sinistra, bus +5V da 3 mm, auto-reset sotto l'ESP32, **pulsanti RESET/BOOT in alto accanto a J3** con scritte in serigrafia, piano GND pieno sul retro, via GND sempre accanto ai pad (mai dentro). Contorno, fori, J1/J2/J3/U1/C1 invariati (il case stampato va ancora bene). Scritta "BARLAROK…" rimessa nella posizione originale sul fronte.
- Tutto il routing è fatto a mano in `BaseChipOnly-backups/relayout-work/relayout.py`, ricostruibile con `build.sh` partendo da `BaseChipOnly-after-fixes-2026-09-30.kicad_pcb`. Versione precedente del PCB: `BaseChipOnly-backups/BaseChipOnly-before-relayout.kicad_pcb`.

Ancora da fare: controllo finale in KiCad GUI, prova al banco dell'auto-reset con esptool, misure sul LED D1 della scheda attuale.

## ✅ Sessione 2026-09-30 — tutti i fix applicati a schematico **e** PCB

**Stato: sorgenti corretti e verificati. Pronto per una revisione finale in KiCad GUI e poi per l'ordine — ma NON ancora testato su hardware.** Le sezioni più sotto (2026-09-28) sono storiche: diverse affermazioni lì sono superate (vedi "Correzioni al log precedente").

Backup pre-sessione: `BaseChipOnly-backups/pre-2026-09-30/`. Lo script che applica tutte le modifiche PCB partendo da quel backup: `BaseChipOnly-backups/fixpcb_2026-09-30.py` (rieseguibile).
Nuovi file di produzione (Gerber, drill, BOM, posizioni, PDF montaggio con valori, PDF schematico): `Esportazione-2026-09-30/`. La vecchia `Esportazione/` non è stata toccata (corrisponde alla scheda già prodotta).

### Schematico (via MCP KiCad)
| # | Fix | Dettaglio |
|---|---|---|
| 9 | TVS | `D_TVS1` → simbolo unidirezionale `Diode:SMAJ5.0A` (SMA). SMF5.0A è in package SOD-123F e non corrispondeva al footprint D_SMA. Catodo (pin 1) su +5V. |
| 4 | L1 | 100µH **Bourns SRN6045TA-101M** (Isat 1.33 A, Irms 0.92 A, DCR 456 mΩ — da datasheet), footprint `L_Bourns_SRN6045TA`. L'MPN precedente (SRP1245A, 12.5 mm) non entrava nel 1210. |
| 5 | Polyfuse1 | 1.5 A hold / 3 A trip, **MF-MSMF150/8X** (8 V, 1812 — da datasheet). MF-RX150 era un radiale THT, incompatibile con lo 0603. ⚠️ Il polyfuse alimenta anche la striscia LED (J2): scegliere la taglia in base all'assorbimento reale della striscia (la serie MSMF arriva a 2.5 A in 1812). |
| 3b | Pulsanti | SW1 **BOOT** (IO0→GND), SW2 **RESET** (EN→GND), C&K PTS810. Reti nominate `IO0` ed `EN`. |
| 10 | COUT2 | 220 µF 6.3 V tantalio case C (6032), in parallelo a COUT1 su +3V3. ESR 0.1–0.5 Ω (non polimero ultra-low-ESR). |
| nuovo | U3 VBUS | Pin 5 di USBLC6 collegato a +5V (riferimento del clamp ESD). |
| — | Rtop1 | Footprint 1210 → 0805 (serve spazio per L1 più grande). |
| — | ERC | No-connect sui 31 pin inutilizzati + PWR_FLAG su +5V/GND/+3V3: **ERC da 39 errori a 0** (restano solo warning di librerie esterne e 6 fili fuori griglia della sessione precedente). |

D1, D2 e circuito auto-reset erano già corretti sullo schematico (sessione 2026-09-28); verificati di nuovo via netlist.

### PCB
| # | Fix |
|---|---|
| 8 | Reference/Value rimessi a posto su tutti i footprint (Reference su F.Silkscreen, Value su F.Fab) e **ricollegati ai simboli dello schematico** (UUID). La parità schematico↔PCB ora è pulita: prima 23 footprint "extra", 19 "mancanti", 20 conflitti di rete. Update-PCB-from-Schematic torna utilizzabile. Per il montaggio a mano: `Esportazione-2026-09-30/BaseChipOnly-assembly-values.pdf` (layer Fab con i valori). |
| 1 | D1 ruotato 180° → K su GND, A verso R0. |
| 2 | D2 ruotato 180° → K su /SW, A su GND (la serigrafia ora è corretta). |
| 3 | Auto-reset rifatto sul rame: RTS → R1 (base IO0_CTRL1) + emettitore EN_CTRL1; DTR → R2 (base EN_CTRL1) + emettitore IO0_CTRL1. Incrocio DTR/RTS con un ponticello su B.Cu; IO13 ri-instradato su B.Cu per liberare il canale; DTR/RTS a 0.15 mm dove corrono a passo 0.4 mm accanto a /SW. |
| 3b | SW1/SW2 sul bordo destro (vicino a J2), vias GND sul piano B.Cu. La scritta "BARLAROK / SmartPlant Trunk / Designed by…" spostata sulla serigrafia **retro** (specchiata, zona x 130–137 / y 65–87) per liberare lo spazio. |
| 4 | L1 nuovo footprint 6×6 mm, COUT1 spostato di 0.5 mm, Rtop1 0805 riposizionato sotto L1; +3V3/SW/FB ri-collegati. Tratti /SW verso L1 e D2 allargati a 0.5 mm. |
| 5 | Polyfuse 1812 in linea con le piste da 3 mm esistenti. |
| 6 | U3 pin 2 → via GND; pin 5 (VBUS) → pista +5V. |
| 7 | Tutte le piste +3V3 portate a 0.5 mm (erano 0.2). |
| 10 | COUT2 in alto a sinistra, collegato a J3 pin 2 (+3V3) e via GND. |
| — | Footprint ESP32: i 12 fori termici del pad esposto (`40_x`) non avevano rete → ora GND. Eliminati 27 errori di clearance, 24 solder-mask-bridge e un "non connesso" preesistenti. |
| — | Serigrafia "GDN" → "GND" (J1 e J2). |

### Verifiche (tutte ripetute sul file finale)
- **Netlist**: diff prima/dopo — cambiano solo le connessioni volute (COUT2, SW1, SW2, U3.5); nessuna fusione di reti.
- **ERC**: 0 errori.
- **DRC con parità schematico** (`kicad-cli pcb drc --schematic-parity`): 0 clearance, 0 corti, 0 non connessi, 0 differenze di parità. Prima: 27 clearance, 23 corti, 4 non connessi, 73 problemi di parità.
- **Gerber X2** del nuovo `F_Cu`: pad→rete verificati per D1, D2, TVS, transistor, R1/R2, U3, L1, polyfuse, SW1/SW2, COUT2 — tutti come da schematico.
- **MCP** `get_component_pads`: stessa conferma per D1, D2, J3, R1, R2, IO0_CTRL1, EN_CTRL1.

### Rimane aperto
- **12 errori DRC "drill 0.2 mm"**: sono i fori termici del footprint ESP32, identici alla scheda già prodotta (la regola della board è 0.3 mm). Accettabili se il fornitore fa fori da 0.2 mm; altrimenti allargarli nel footprint.
- Warning solo estetici di serigrafia (testi sovrapposti/su rame, altezza testo) — da rifinire a mano in KiCad GUI se si vuole.
- 6 fili fuori griglia nello schematico (sessione precedente): solo igiene grafica.
- **LED D1 spento anche montato girato** (vedi `docs/hardware-reviews/base-chiponly-fixes.md`, "Open issues"): la polarità ora è giusta, ma la causa del guasto sulla scheda attuale non è ancora diagnosticata.
- **Auto-reset**: il circuito incrociato è quello standard, ma va verificato al banco con esptool prima di ordinare in quantità.
- Taglia del polyfuse rispetto alla corrente della striscia LED (vedi sopra).
- MPN di COUT2 da scegliere al momento dell'ordine.
- Le librerie `USBC` (ESP32, barrel jack, morsetto) non sono nella tabella librerie del progetto: warning ERC/DRC `footprint_link_issues`, nessun effetto sul rame.

### Correzioni al log precedente (2026-09-28)
- "L1 footprint aggiornato su schematico e PCB": **falso per il PCB** — il footprint PCB era ancora 1008. Corretto ora.
- "MPN SRP1245A-101M (1210)": l'SRP1245A misura 12.5 mm, non 1210. Sostituito.
- "MF-RX150" su footprint 0603: incompatibile (radiale THT). Sostituito.

---

# Log sessioni precedenti (2026-09-28) — storico

Progetto: `BaseChipOnly_rev2/BaseChipOnly.kicad_pro`
Lista fix originale: batch concordato durante il bring-up 2026-07/08 (vedi memoria `basechiponly-pending-fixes`).

**Stato generale: NON pronto per una nuova produzione.** Sessione di follow-up in corso (2026-09-28, seconda parte): D2 ora corretto **sullo schematico** (verificato via netlist), ma il fix **non è ancora propagato al PCB** — vedi punto 2 aggiornato sotto per una scoperta importante che blocca la sincronizzazione automatica schema→PCB su questo progetto.

---

## Fatto e verificato (via netlist re-esportato, non solo per lettura del file)

### 4. L1 (induttore buck) — ✅ FATTO
- Valore: `100µH`, MPN proposto `SRP1245A-101M` (Bourns, 1210, Isat dichiarato ~1.5A)
- Footprint aggiornato su schematico e PCB: `Inductor_SMD:L_1210_3225Metric`
- **Da verificare ancora**: datasheet del MPN non recuperato in questa sessione (verificare Isat/DCR prima di ordinare); clearance/courtyard con COUT1 e U4 non ricontrollata dopo il cambio di footprint più grande.

### 5. Polyfuse1 (12A → 1.5A) — ✅ FATTO
- Valore: `1.5A`, MPN proposto `MF-RX150` (Bourns)
- **Da verificare**: datasheet del MPN non controllato; footprint/package non validato per compatibilità con l'impronta esistente.

### 6. U3 (USBLC6-2SC6) pin GND scollegato — ✅ FATTO e confermato
- Il pin 2 (GND) era su una rete isolata propria, non collegato al GND globale.
- Aggiunto stub/etichetta di rete: ora il pin 2 risulta correttamente sulla rete `GND`.
- Modifica additiva, a basso rischio (non toccava wire esistenti).

---

## NON fatto — bloccato deliberatamente per rischio

### 1. D1 (LED di stato invertito) — ✅ SCHEMATICO FATTO e verificato (2026-09-28, seconda sessione), PCB non ancora aggiornato
- Fix fatto a livello di wire (non rotazione): cancellati i due stub di filo ai pin di D1, ridisegnati con un piccolo detour per scambiare le connessioni senza attraversare l'altro pin (che avrebbe causato un corto pin1-pin2):
  - Filo dal ramo R0 ora arriva al pin 2 (A) invece che al pin 1 (K)
  - Filo dal simbolo GND (#PWR06) ora arriva al pin 1 (K) invece che al pin 2 (A)
- **Verificato via netlist re-esportato**: D1 ora `K→GND`, `A→(rete verso R0)→+5V`. Catena corretta: +5V → R0 → anodo → catodo → GND. Rete GND: 48 pin, rete +5V: 16 pin — nessuna fusione anomala rispetto al baseline.
- **PCB non ancora aggiornato** — stesso blocco descritto al punto 2 (sync_schematic_to_board non sicuro su questo progetto finché il punto 8 non è risolto).
- Nota indipendente dalla polarità, ancora valida: durante il bring-up il LED restava spento **anche con polarità invertita manualmente e con LED sostituito** — quindi il fix schematico non garantisce che il LED si accenda; serve comunque un retest su hardware fisico per la causa non diagnosticata.

### 2. D2 (diodo di catch SS34 invertito) — ⚠️ SCHEMATICO FATTO e verificato, PCB ancora NO
**Schematico — fatto 2026-09-28, verificato via netlist:**
- Niente rotazione automatica questa volta (quella tentata nella sessione precedente aveva quasi fuso /SW con GND — vedi nota storica sotto). Fix fatto a livello di wire, senza muovere il simbolo D2:
  1. Cancellato il filo diagonale che collegava il pin 2 (A) di D2 al nodo /SW.
  2. Spostato il simbolo di potenza `#PWR035` (GND) dalla posizione del pin 1 (K) a quella del pin 2 (A).
  3. Ridisegnato il filo dal pin 1 (K) verso il nodo /SW (giunzione con il filo esistente verso L1/U4).
- **Verificato via netlist re-esportato**: D2 ora `K→SW`, `A→GND`. Rete GND: 48 pin (nessuna fusione anomala), rete SW: 3 pin (U4 OUT, L1 pin1, D2 K) — corretto, nessun corto introdotto.

**PCB — non ancora aggiornato, e scoperto un blocco serio per la sincronizzazione automatica:**
- Ho provato a propagare la modifica al PCB con `sync_schematic_to_board` (equivalente a F8 "Update PCB from Schematic"). Il risultato è stato pericoloso: ha tentato di aggiungere **17 footprint duplicati** (inclusi un secondo D2, un secondo D_TVS1, ecc.) invece di aggiornare quelli esistenti.
- **Causa**: lo strumento abbina schematico↔PCB per *reference designator*, ma su questo PCB — a causa del bug del punto 8 — molti footprint hanno il campo **Reference interno** impostato al valore (es. il footprint di D2 ha come Reference "SS34", non "D2"), non solo la serigrafia. Quindi lo schematico "D2" non trova corrispondenza e viene aggiunto come nuovo componente orfano.
- **Non è stato salvato su disco** (il backend ha rifiutato l'auto-save perché il file PCB era cambiato esternamente nel frattempo, probabilmente perché aperto anche in KiCad GUI) — quindi nessun danno permanente. Ho ricaricato il progetto e confermato che il PCB su disco è tornato pulito (31 footprint, nessun duplicato).
- **Conclusione operativa**: finché il punto 8 (Reference/Value scambiati) non è corretto, `sync_schematic_to_board`/F8 **non è sicuro da usare su questo progetto** — rischia di duplicare footprint invece di aggiornarli. Il fix del PCB per D2 (ri-orientare il footprint fisico + eventualmente le tracce di rame già instradate sul vecchio net) va quindi fatto **manualmente**, dopo aver sistemato il punto 8.
- **Fino ad allora resta valida la nota della sessione precedente**: saldare l'SS34 con la banda del catodo sul pad inferiore (verso L1/pin2 LM2596), opposto alla serigrafia — vedi memoria `basechiponly-d2-reversed`.

*Nota storica (sessione precedente, 2026-09-28 prima parte)*: un primo tentativo aveva usato `rotate_schematic_component` per "ruotare" D2 di 180°, che invece di scambiare le reti ha fuso /SW con GND (quasi-corto). Annullato subito. Il fix di questa sessione ha evitato del tutto quel tool, usando editing esplicito dei fili — vedi memoria `kicad-mcp-rotate-tool-unreliable`.

### 3. Circuito auto-reset (DTR/RTS incrociati) — ✅ SCHEMATICO FATTO e verificato (2026-09-28, seconda sessione)
Stato di partenza confermato:
- J3 pin 5 = DTR, pin 6 = RTS
- IO0_CTRL1 base ← DTR (via R1); EN_CTRL1 base ← RTS (via R2)
- Entrambi gli emettitori → GND (bug: mai va in download mode)

**Modifiche fatte** (editing esplicito dei fili, nessuna rotazione):
1. R1 pin1: scollegato da DTR, ricollegato a RTS (J3 pin6) → base IO0_CTRL1 ora ← RTS
2. R2 pin2: scollegato da RTS, ricollegato a DTR (J3 pin5) → base EN_CTRL1 ora ← DTR
3. Emettitore IO0_CTRL1: rimosso il simbolo GND dedicato (`#PWR017`, era coincidente col pin), ricollegato a DTR (J3 pin5)
4. Emettitore EN_CTRL1: scollegato dal ramo GND, ricollegato a RTS (J3 pin6)

**Incidente rilevato e corretto durante il fix**: il primo routing del filo dell'emettitore IO0_CTRL1 verso DTR passava in verticale esattamente sopra il pin RTS di J3 (stesso x, range y che lo attraversava), **fondendo DTR e RTS in un'unica rete**. Rilevato immediatamente ri-esportando il netlist (DTR e RTS risultavano sullo stesso net), cancellato il filo e ridisegnato con una colonna x diversa che evita la fila di pin di J3. Riverificato: DTR e RTS di nuovo su reti separate.

**Verificato via netlist finale**:
- IO0_CTRL1: base←RTS (via R1), emettitore←DTR, collettore invariato (rete IO0/R3 pull-up)
- EN_CTRL1: base←DTR (via R2), emettitore←RTS, collettore invariato (rete EN/R4 pull-up)
- Corrisponde esattamente al target incrociato. Nessun emettitore più su GND.

Tabella di verità (logica diretta, non invertita, da chip USB-seriale):

| DTR | RTS | EN tirato basso (reset) | IO0 tirato basso (bootloader) |
|---|---|---|---|
| 1 | 1 | No | No |
| 1 | 0 | Sì | No |
| 0 | 1 | No | Sì |
| 0 | 0 | No | No |

**PCB non ancora aggiornato** — stesso blocco del punto 2 (sync schema→PCB non sicuro finché il punto 8 non è risolto). Il circuito di auto-reset resta corretto solo sullo schematico per ora.

### 3b. Pulsanti BOOT/RESET — ❌ NON TENTATO
Rimandato: dipende dal punto 3 (serve sapere su quali reti finali attestare i pulsanti prima di piazzarli).

### 7. Tracce +3V3 troppo strette — ❌ NON TENTATO (tempo)

### 8. Reference/Value scambiati sul silkscreen — ❌ NON CORRETTO, confermato presente
Osservato direttamente: i riferimenti mostrati sul PCB sono letteralmente i *valori* dei componenti (`12A`, `470Ω`, `2.1mm`) invece dei designatori (`Polyfuse1`, `R0`, `MountingHole1`). Questo corrompe BOM e file pick-and-place. Da correggere su tutti i 31 footprint — non fatto per tempo.

### 9. D_TVS1 (simbolo bidirezionale su SMF5.0A unidirezionale) — ❌ NON TENTATO
Stesso rischio di modifica-simbolo dei punti 1-2, rimandato.

### 10. COUT1 — aggiunta capacità bulk per stabilità anello LM2596 — ❌ NON TENTATO (tempo)

### 11. Correzione doc `docs/hardware-reviews/base-chiponly-review.md` — ❌ NON TENTATO
Percorso del documento non individuato in questa sessione (da cercare nel repo principale, fuori da questa cartella BaseChipOnly_rev2).

---

## Verifiche fatte

- **LM2596 Vout — calcolato, non simulato**: Vout = 1.23V × (1 + Rtop1/Rbot1) = 1.23 × (1 + 2.0k/1.2k) ≈ **3.28V**. Il partitore di feedback (Rtop1=2.0k, Rbot1=1.2k) è dimensionato correttamente, nessuna modifica necessaria lì. Nota: calcolo a mano, non una simulazione SPICE reale — utile solo come controllo di coerenza.
- **ERC/DRC**: eseguiti dopo le modifiche — 44 violazioni ERC (39 errori, per lo più pin GPIO ESP32 non connessi + percorsi libreria footprint mancanti, sembrano preesistenti) e 93 violazioni DRC. **Non è stato catturato un baseline pre-modifica**, quindi non è possibile distinguere con certezza cosa fosse già presente prima da cosa (se qualcosa) sia stato introdotto dalle modifiche di questa sessione. Da rifare con baseline per un giudizio pulito.
- **ERC ri-eseguito dopo la seconda sessione (D1/D2/auto-reset)**: 50 violazioni (39 errori, 11 warning), conteggio errori identico alla sessione precedente (39) — coerente col fatto che le nuove modifiche non abbiano introdotto nuovi errori critici. Compaiono nuovi **warning "pin/capo filo fuori griglia"** su alcuni dei nuovi fili aggiunti (i jog di routing usati per evitare di attraversare altri pin non sono sempre caduti sulla griglia standard 1.27mm) — non è un errore di connettività (verificato via netlist, non via griglia), ma andrebbe ripulito in KiCad GUI per igiene dello schematico prima del fab.

## ⚠️ Incidente serio (2026-09-28, seconda sessione): footprint duplicati salvati su disco
Il tentativo di `sync_schematic_to_board` della sessione precedente aveva aggiunto 17 footprint duplicati (non piazzati, a coordinate 0,0) a causa del bug del punto 8 (vedi sopra). Nonostante il messaggio "auto-save refused" ricevuto allora, **questi duplicati risultavano effettivamente salvati su disco**: il file PCB è passato da 31 a 48 blocchi footprint. Questa cartella BaseChipOnly_rev2 **non è tracciata da git**, quindi non c'era uno storico da cui recuperare.

Ho rimosso 15 dei 17 duplicati nella sessione precedente. **I 2 rimanenti (D2 e COUT1 orfani a coordinate 0,0) sono stati rimossi con conferma esplicita dell'utente** (2026-09-28, terza sessione): verificati via `find_component` (matchCount:1, posizione 0,0, distinti dagli originali reali "SS34"@143.45,49.53 e "47µF"@134.25,46.85), cancellati con `delete_component`, board salvata e ricontata: **31 footprint sul file su disco — corretto**.
**Stato attuale: risolto. Il PCB ha di nuovo il conteggio footprint corretto (31).**

## File modificati in questa sessione (aggiornato, seconda sessione 2026-09-28)
- `BaseChipOnly.kicad_sch`: 
  - D1: polarità corretta (fix wire-level, verificato via netlist)
  - D2: polarità corretta (fix wire-level, verificato via netlist)
  - Circuito auto-reset: IO0_CTRL1/EN_CTRL1 base ed emettitore ricablati (DTR/RTS incrociati), verificato via netlist
  - L1 (valore/MPN), Polyfuse1 (valore/MPN), U3 (stub GND aggiunto) — dalla sessione precedente, ancora validi
- `BaseChipOnly.kicad_pcb`:
  - footprint L1 aggiornato (sessione precedente)
  - **15 footprint duplicati orfani rimossi** (residuo pericoloso del tentativo di sync della sessione precedente, che risultava salvato su disco nonostante l'avviso contrario)
  - **2 footprint duplicati (D2, COUT1) ancora presenti — richiedono rimozione manuale**, vedi sezione incidente sopra
  - D1, D2, circuito auto-reset: **fix NON ancora propagati al PCB** (bloccato dal bug del punto 8, vedi sopra)

## Conclusione
**Non ordinare Gerber/fab da questo stato.** Lato schematico, i tre fix più critici (D1, D2, auto-reset) sono ora corretti e verificati via netlist. Ma:
1. Nessuno di questi fix è ancora arrivato al PCB (il rame è ancora instradato secondo la vecchia connettività bacata).
2. ~~Il PCB ha ancora 2 footprint duplicati orfani da rimuovere manualmente.~~ **Risolto 2026-09-28**: i 2 duplicati rimasti sono stati rimossi con conferma dell'utente, PCB tornato a 31 footprint corretti.
3. Il bug del punto 8 (Reference/Value scambiati) blocca la sincronizzazione automatica schema→PCB e va risolto per primo prima di ogni altro lavoro sul PCB.
4. Punti 3b, 4 (già fatto), 5 (già fatto), 7, 9, 10, 11 restano da fare come da sezioni sopra.

**Prossimo passo consigliato**: risolvere il punto 8 (Reference/Value sui footprint) — è un fix a basso rischio (campi testo, non fili) e sblocca la sincronizzazione sicura schema→PCB necessaria per portare D1/D2/auto-reset dallo schematico al rame reale.

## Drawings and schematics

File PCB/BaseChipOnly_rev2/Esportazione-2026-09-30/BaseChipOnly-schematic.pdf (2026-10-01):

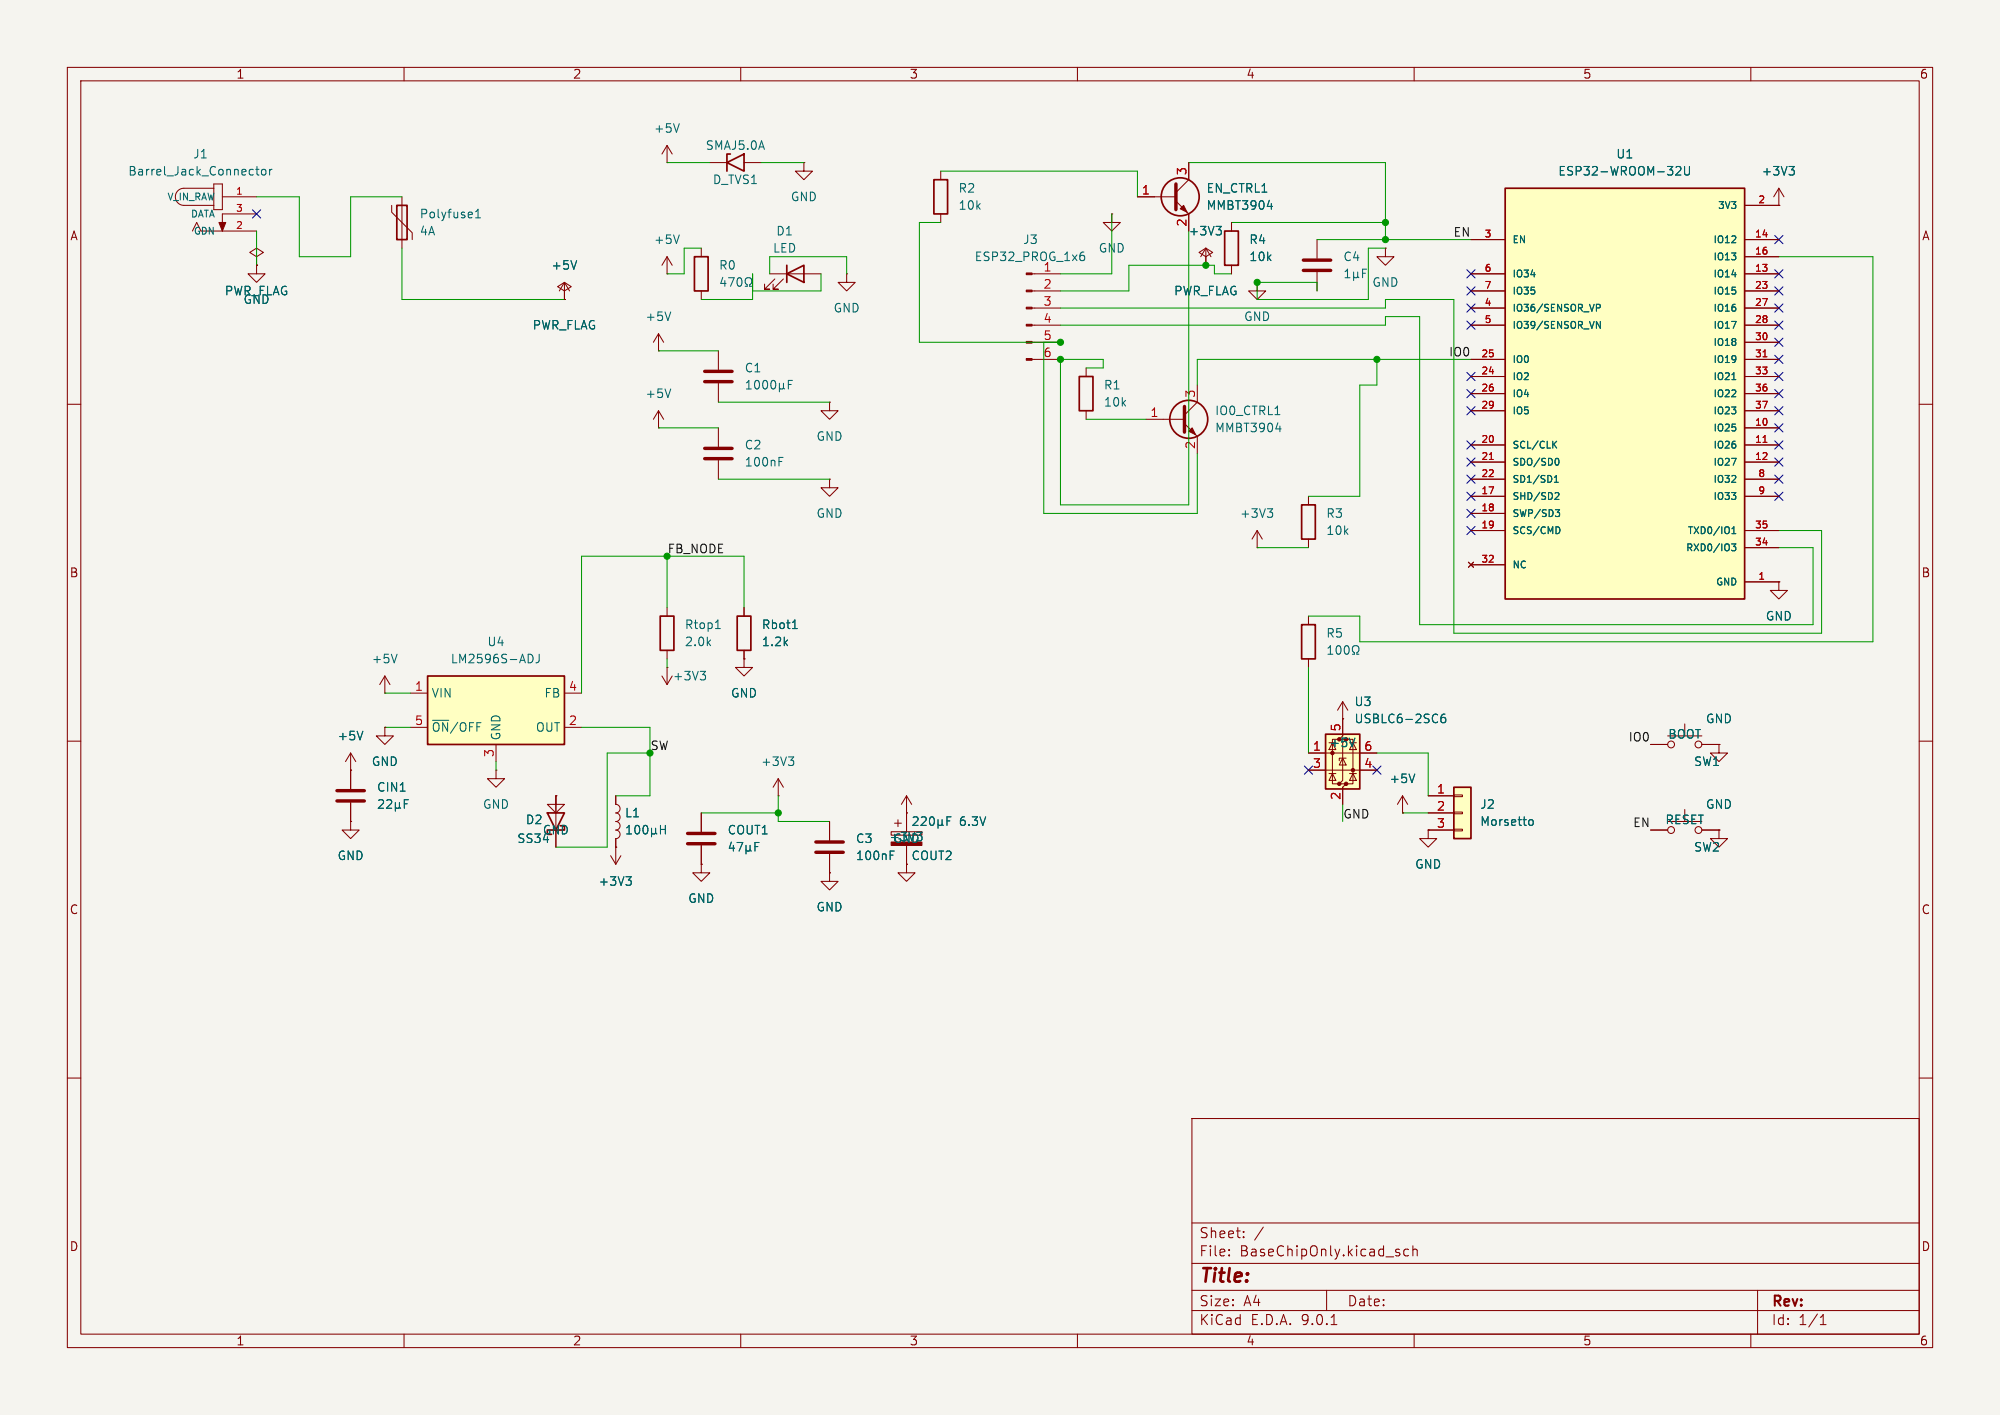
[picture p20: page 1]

Id: 1/1 Title: File: BaseChipOnly.kicad_sch Sheet: /

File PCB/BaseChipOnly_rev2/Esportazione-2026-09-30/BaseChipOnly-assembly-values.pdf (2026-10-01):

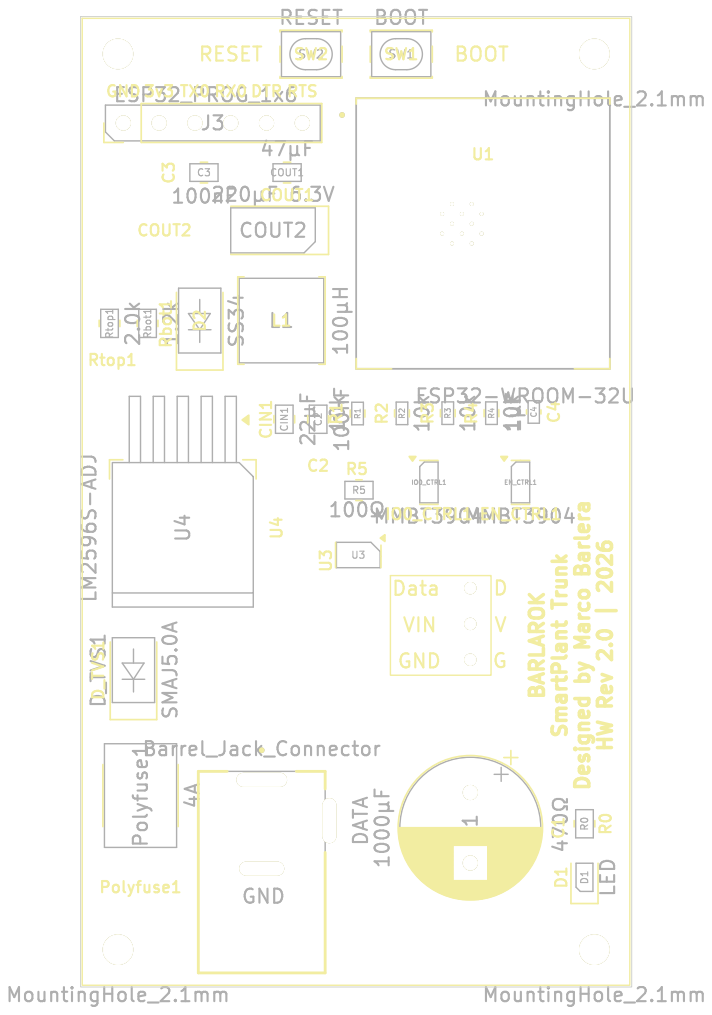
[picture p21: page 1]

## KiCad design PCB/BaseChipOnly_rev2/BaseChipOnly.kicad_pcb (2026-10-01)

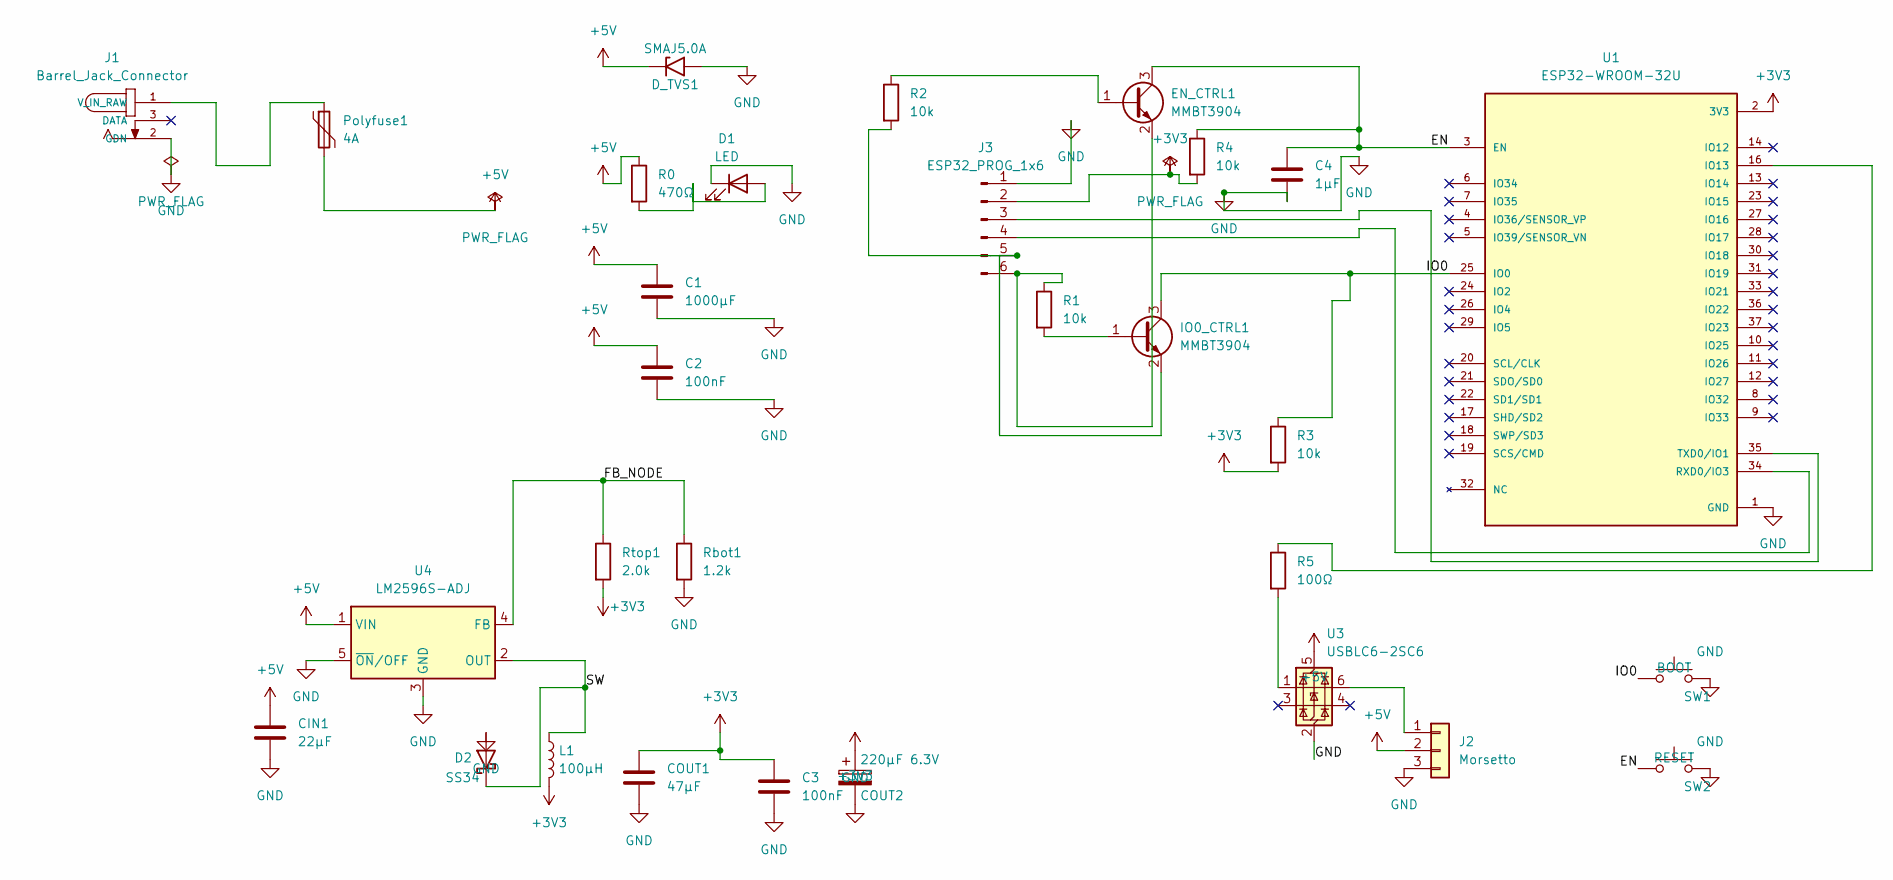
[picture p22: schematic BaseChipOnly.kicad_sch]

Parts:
C1: 1000µF; CP_Radial_D10.0mm_P5.00mm
C2, C3: 100nF; C_0805_2012Metric_Pad1.18x1.45mm_HandSolder
C4: 1µF; C_0603_1608Metric_Pad1.08x0.95mm_HandSolder
CIN1: 22µF; C_0805_2012Metric_Pad1.18x1.45mm_HandSolder
COUT1: 47µF; C_0805_2012Metric_Pad1.18x1.45mm_HandSolder
COUT2: 220µF 6.3V; CP_EIA-6032-28_Kemet-C_HandSolder; MPN TPSC227M006R0100
D1: LED; LED_0805_2012Metric_Pad1.15x1.40mm_HandSolder
D2: SS34; D_SMA
D_TVS1: SMAJ5.0A; D_SMA; MPN SMAJ5.0A
EN_CTRL1: MMBT3904; SOT-23; MPN MMBT3904
IO0_CTRL1: MMBT3904; SOT-23; MPN MMBT3904
J1: Barrel_Jack_Connector; BarrelJack
J2: Morsetto; Morsetto_3_Vie
J3: ESP32_PROG_1x6; PinHeader_1x06_P2.54mm_Vertical
L1: 100µH; L_Bourns_SRN6045TA; MPN SRN6045TA-101M
Polyfuse1: 4A; Fuse_2920_7451Metric_Pad2.10x5.45mm_HandSolder; MPN MF-LSMF400/12X
R0: 470Ω; R_0805_2012Metric_Pad1.20x1.40mm_HandSolder
R1, R2, R3, R4: 10k; R_0603_1608Metric_Pad0.98x0.95mm_HandSolder
R5: 100Ω; R_0805_2012Metric_Pad1.20x1.40mm_HandSolder
Rbot1: 1.2k; R_0805_2012Metric_Pad1.20x1.40mm_HandSolder
Rtop1: 2.0k; R_0805_2012Metric_Pad1.20x1.40mm_HandSolder
SW1: BOOT; SW_SPST_PTS810; MPN PTS810 SJM 250 SMTR LFS
SW2: RESET; SW_SPST_PTS810; MPN PTS810 SJM 250 SMTR LFS
U1: ESP32-WROOM-32U; XCVR_ESP32-WROOM-32U; PARTREV 2.4
U3: USBLC6-2SC6; SOT-23-6_Handsoldering
U4: LM2596S-ADJ; TO-263-5_TabPin3

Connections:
+3V3: C3.1, COUT1.1, COUT2.1, J3.2 (3V3), L1.2, R3.2, R4.2, Rtop1.2, U1.2 (3V3)
+5V: C1.1, C2.1, CIN1.1, D_TVS1.1 (A1), J2.2, Polyfuse1.2, R0.1, U3.5 (VBUS), U4.1 (VIN)
/EN: C4.1, EN_CTRL1.3 (C), R4.1, SW2.1, U1.3 (EN)
/FB_NODE: Rbot1.1, Rtop1.1, U4.4 (FB)
/IO0: IO0_CTRL1.3 (C), R3.1, SW1.1, U1.25 (IO0)
/SW: D2.1 (K), L1.1, U4.2 (OUT)
GND: C1.2, C2.2, C3.2, C4.2, CIN1.2, COUT1.2, COUT2.2, D1.1 (K), D2.2 (A), D_TVS1.2 (A2), J1.2 (GDN), J2.3, J3.1 (GND), Rbot1.2, SW1.2, SW2.2, U1.1 (GND), U1.15 (GND), U1.38 (GND), U1.39_1 (GND), U1.39_2 (GND), U1.39_3 (GND), U1.39_4 (GND), U1.39_5 (GND), U1.39_6 (GND), U1.39_7 (GND), U1.39_8 (GND), U1.39_9 (GND), U3.2 (GND), U4.3 (GND), U4.5 (~ON/OFF)
unnamed: D1.2 (A), R0.2
unnamed: EN_CTRL1.1 (B), R2.1
unnamed: EN_CTRL1.2 (E), J3.6 (RTS), R1.1
unnamed: IO0_CTRL1.1 (B), R1.2
unnamed: IO0_CTRL1.2 (E), J3.5 (DTR), R2.2
unnamed: J1.1 (V_IN_RAW), Polyfuse1.1
unnamed: J2.1, U3.6 (I/O1)
unnamed: J3.4 (RX0), U1.34 (RXD0/IO3)
unnamed: J3.3 (TX0), U1.35 (TXD0/IO1)
unnamed: R5.2, U3.1 (I/O1)
unnamed: R5.1, U1.16 (IO13)

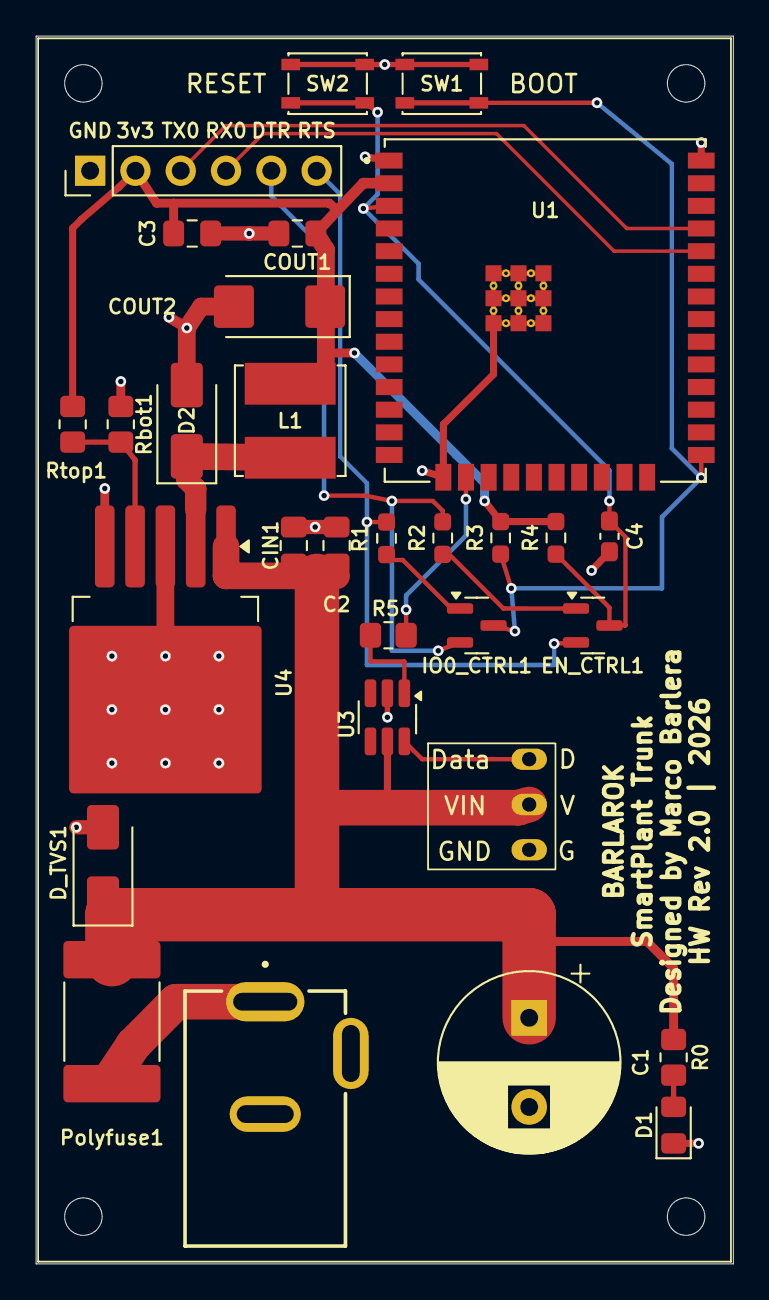
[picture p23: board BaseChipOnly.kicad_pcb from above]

Board: 2 copper layers, 39.1 x 68.8 mm, 34 parts (0 on the bottom side), 18 nets.

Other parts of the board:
H1, H2, H3, H4: MountingHole_2.1mm

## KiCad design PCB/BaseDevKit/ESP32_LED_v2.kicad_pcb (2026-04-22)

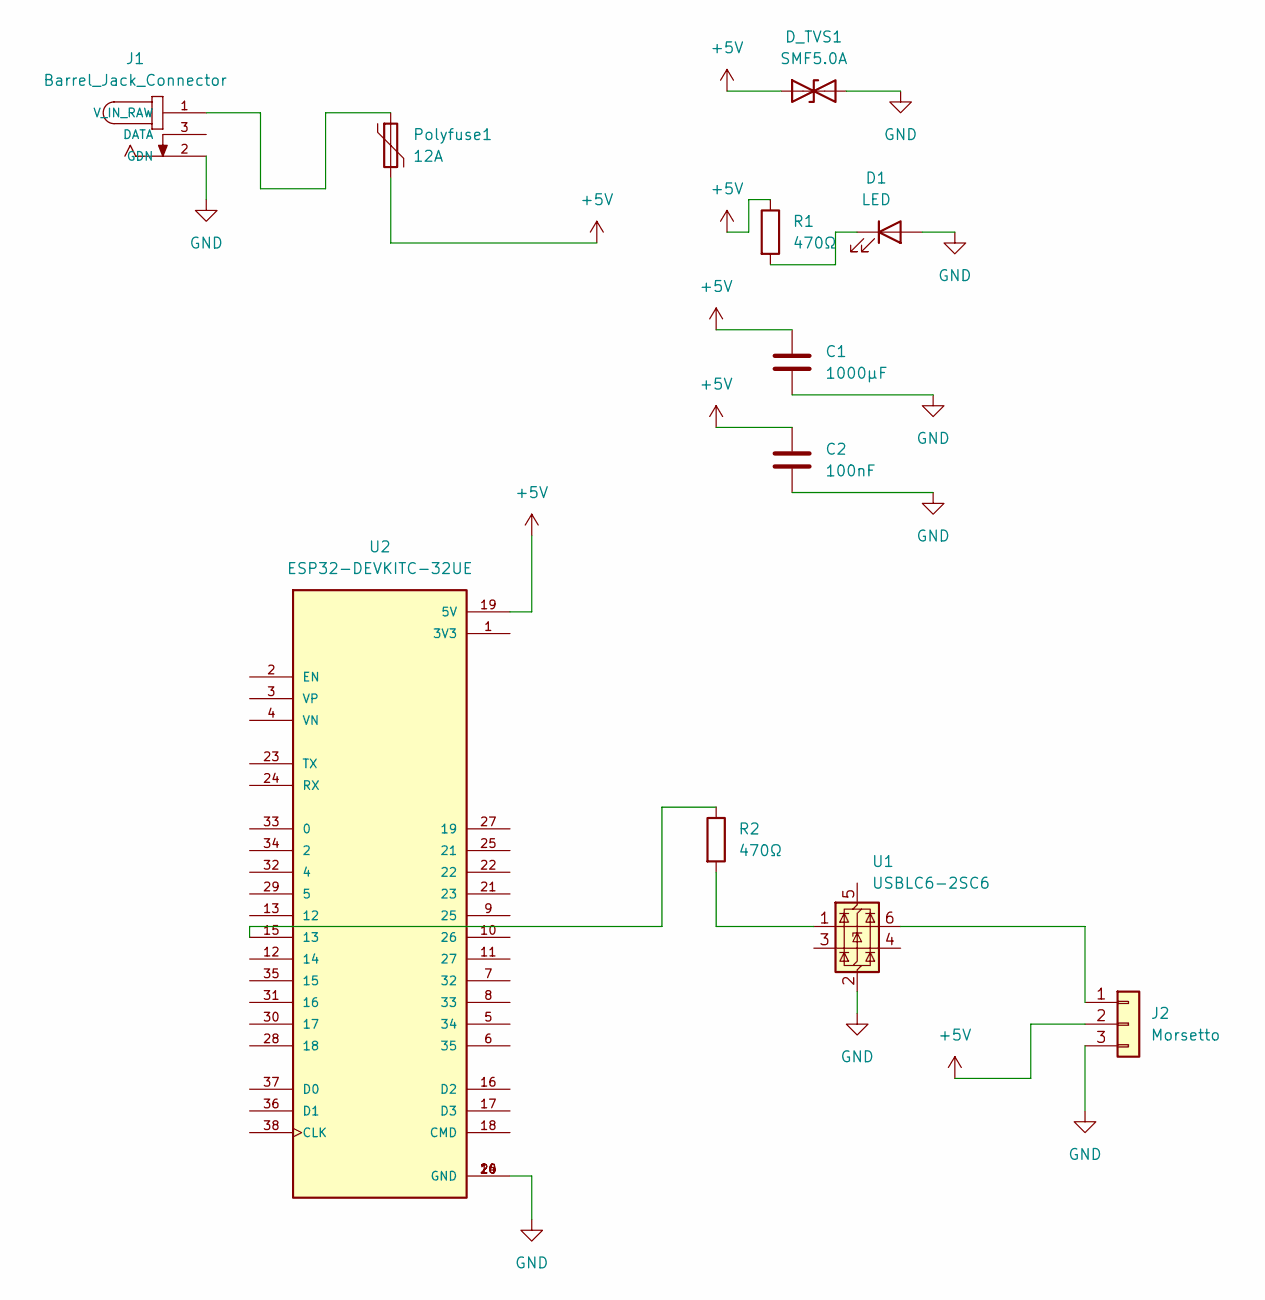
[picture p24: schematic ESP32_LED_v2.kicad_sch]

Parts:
C1: 1000µF; CP_Radial_D10.0mm_P5.00mm
C2: 100nF; C_0805_2012Metric_Pad1.18x1.45mm_HandSolder
D1: LED; LED_0402_1005Metric
D_TVS1: SMF5.0A; D_SMA
J1: Barrel_Jack_Connector; BarrelJack
J2: Morsetto; Morsetto_3_Vie
Polyfuse1: 12A; Fuse_0603_1608Metric_Pad1.05x0.95mm_HandSolder
R1, R2: 470Ω; R_0805_2012Metric_Pad1.20x1.40mm_HandSolder
U1: USBLC6-2SC6; SOT-23-6_Handsoldering
U2: ESP32-DEVKITC-32UE; ESPRESSIF_ESP32-DEVKITC-32UE

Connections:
+5V: C1.1, C2.1, D_TVS1.1 (A1), J2.2, Polyfuse1.2, R1.1, U2.19 (5V)
GND: C1.2, C2.2, D1.2 (A), D_TVS1.2 (A2), J1.2 (GDN), J2.3, U1.2 (GND), U2.14 (GND), U2.20 (GND), U2.26 (GND)
unnamed: D1.1 (K), R1.2
unnamed: J1.1 (V_IN_RAW), Polyfuse1.1
unnamed: J2.1, U1.6 (I/O1)
unnamed: R2.2, U1.1 (I/O1)
unnamed: R2.1, U2.15 (13)

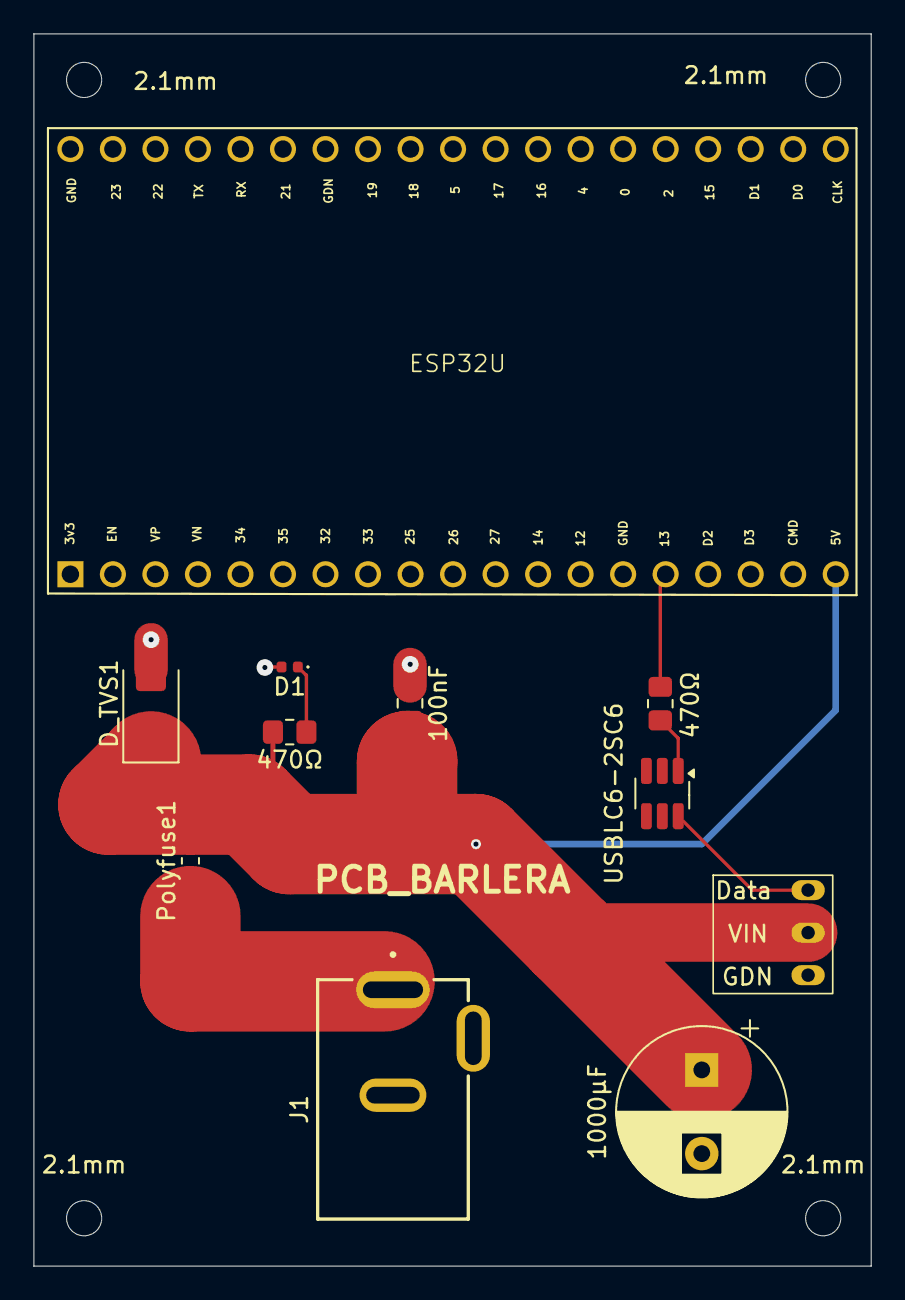
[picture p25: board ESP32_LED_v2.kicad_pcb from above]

Board: 2 copper layers, 50.0 x 73.6 mm, 15 parts (0 on the bottom side), 7 nets.

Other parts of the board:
2.1mm, 2.1mm#2, 2.1mm#3, 2.1mm#4: MountingHole_2.1mm

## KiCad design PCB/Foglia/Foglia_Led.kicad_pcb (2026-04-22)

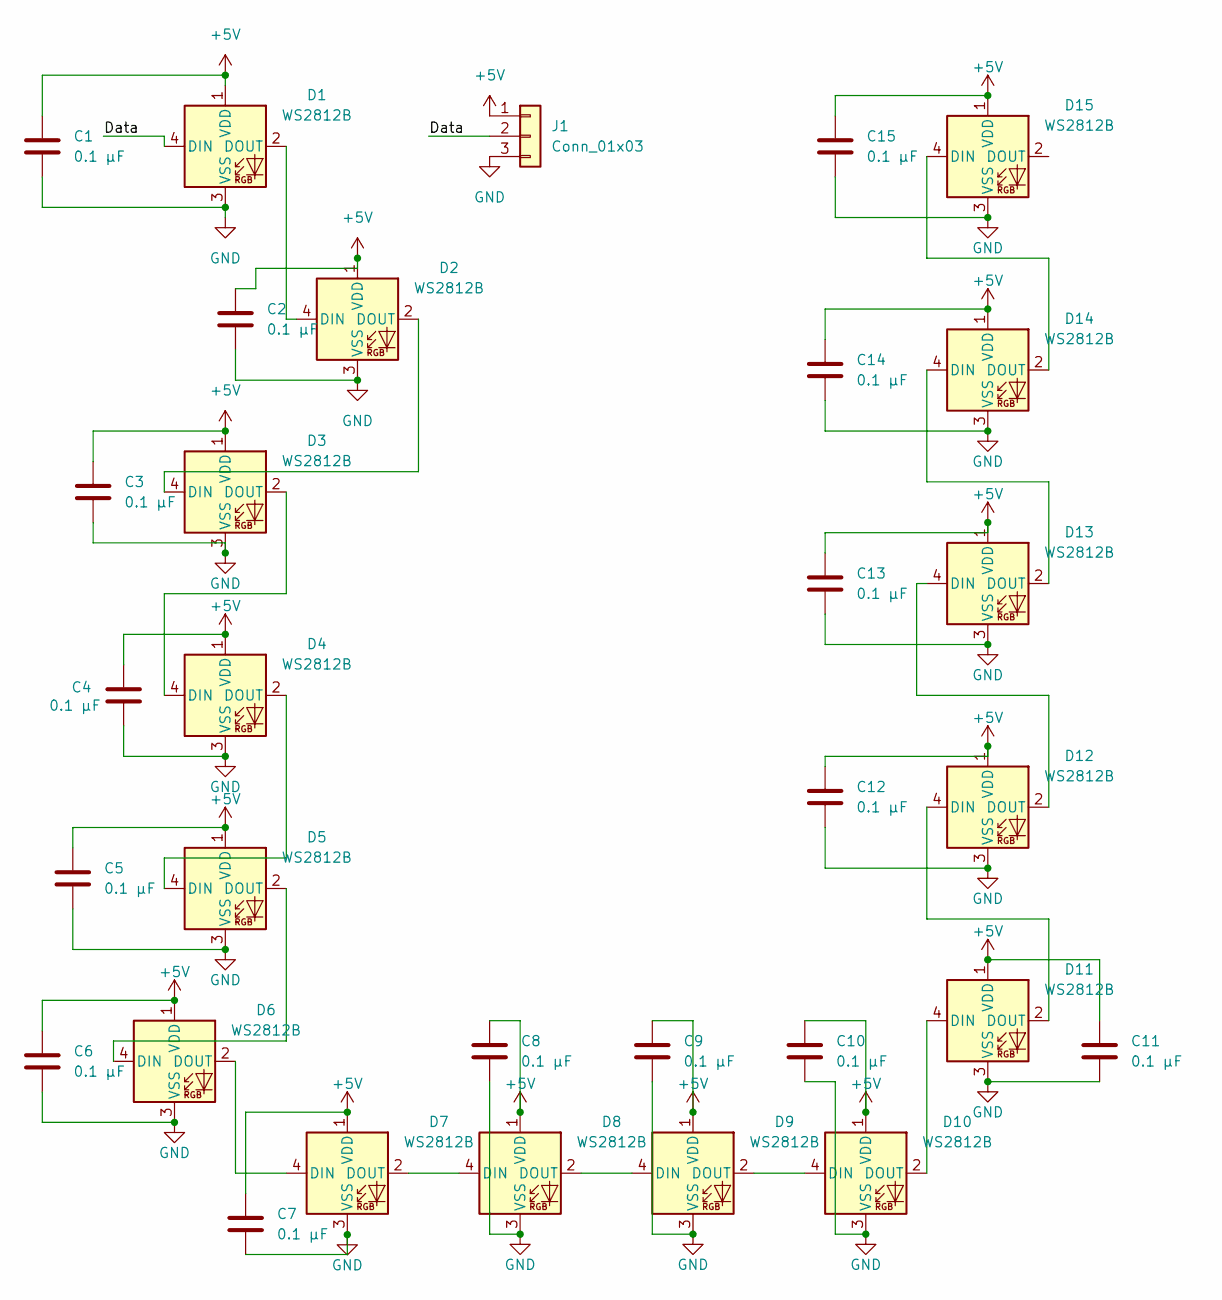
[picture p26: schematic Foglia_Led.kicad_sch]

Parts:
C1, C2, C3, C4, C5, C6, C7, C8, C9, C10, C11, C12, C13, C14, C15: 0.1 µF; C_0603_1608Metric_Pad1.08x0.95mm_HandSolder
D1, D2, D3, D4, D5, D6, D7, D9, D10, D11, D12, D13, D14, D15: WS2812B; LED_WS2812B_PLCC4_5.0x5.0mm_P3.2mm
D8: WS2812B; Led_Verticale
J1: Conn_01x03; Pad_LEd

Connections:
+5V: C1.1, C2.1, C3.1, C4.1, C5.1, C6.1, C7.1, C8.1, C9.1, C10.1, C11.1, C12.1, C13.1, C14.1, C15.1, D1.1 (VDD), D2.1 (VDD), D3.1 (VDD), D4.1 (VDD), D5.1 (VDD), D6.1 (VDD), D7.1 (VDD), D8.1 (VDD), D9.1 (VDD), D10.1 (VDD), D11.1 (VDD), D12.1 (VDD), D13.1 (VDD), D14.1 (VDD), D15.1 (VDD), J1.1
/Data: D1.4 (DIN), J1.2
GND: C1.2, C2.2, C3.2, C4.2, C5.2, C6.2, C7.2, C8.2, C9.2, C10.2, C11.2, C12.2, C13.2, C14.2, C15.2, D1.3 (VSS), D2.3 (VSS), D3.3 (VSS), D4.3 (VSS), D5.3 (VSS), D6.3 (VSS), D7.3 (VSS), D8.3 (VSS), D9.3 (VSS), D10.3 (VSS), D11.3 (VSS), D12.3 (VSS), D13.3 (VSS), D14.3 (VSS), D15.3 (VSS), J1.3
unnamed: D1.2 (DOUT), D2.4 (DIN)
unnamed: D2.2 (DOUT), D3.4 (DIN)
unnamed: D3.2 (DOUT), D4.4 (DIN)
unnamed: D4.2 (DOUT), D5.4 (DIN)
unnamed: D5.2 (DOUT), D6.4 (DIN)
unnamed: D6.2 (DOUT), D7.4 (DIN)
unnamed: D7.2 (DOUT), D8.4 (DIN)
unnamed: D8.2 (DOUT), D9.4 (DIN)
unnamed: D9.2 (DOUT), D10.4 (DIN)
unnamed: D10.2 (DOUT), D11.4 (DIN)
unnamed: D11.2 (DOUT), D12.4 (DIN)
unnamed: D12.2 (DOUT), D13.4 (DIN)
unnamed: D13.2 (DOUT), D14.4 (DIN)
unnamed: D14.2 (DOUT), D15.4 (DIN)

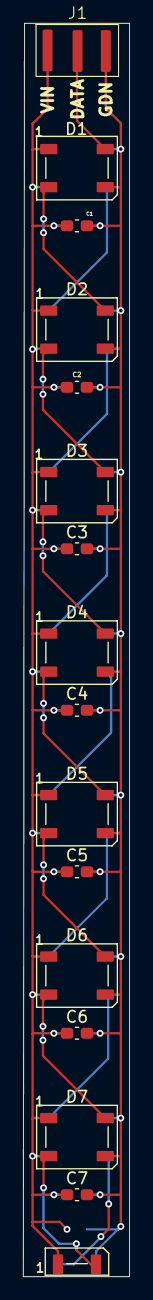
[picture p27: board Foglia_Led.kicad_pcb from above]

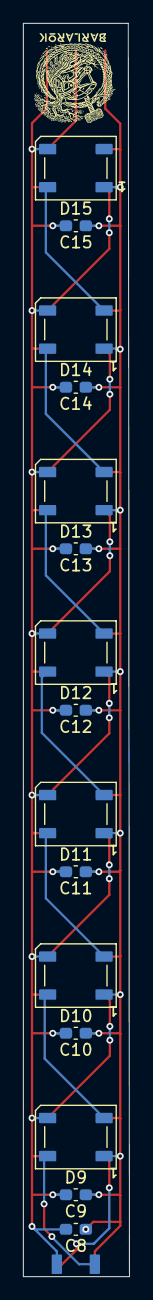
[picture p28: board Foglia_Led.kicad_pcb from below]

Board: 2 copper layers, 9.2 x 108.6 mm, 31 parts (15 on the bottom side), 17 nets.

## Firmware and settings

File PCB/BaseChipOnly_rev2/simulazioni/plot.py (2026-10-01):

"""Plots for the BaseChipOnly simulations (reads out/*.dat written by ngspice wrdata)."""
import numpy as np, matplotlib
matplotlib.use('Agg')
import matplotlib.pyplot as plt

def load(f, n):
    a = np.loadtxt(f)
    return a[:, 0], [a[:, 2 * k + 1] for k in range(n)]

def style(ax, title, ylabel):
    ax.set_title(title, fontsize=10, loc='left'); ax.set_ylabel(ylabel); ax.grid(alpha=.3)

# 01 auto-reset: new circuit vs rev 1.03
for fn, tag in (('01_autoreset', 'nuovo circuito (C4 100 nF)'), ('01c_autoreset_C4_1u', 'nuovo circuito, C4 = 1 µF'),
                ('01b_autoreset_rev103', 'rev 1.03 come prodotta')):
    t, (dtr, rts, en, io0) = load(f'out/{fn}.dat', 4)
    fig, ax = plt.subplots(2, 1, figsize=(10, 5.5), sharex=True)
    ax[0].plot(t*1e3, dtr, label='pin DTR'); ax[0].plot(t*1e3, rts, '--', label='pin RTS')
    style(ax[0], f'Auto-reset — {tag}: segnali dall\'adattatore', 'V'); ax[0].legend(loc='right', fontsize=8)
    ax[1].plot(t*1e3, en, label='EN (CHIP_PU)'); ax[1].plot(t*1e3, io0, label='IO0')
    ax[1].axhline(2.475, color='gray', ls=':', lw=1); ax[1].text(805, 2.5, 'soglia alta 2.475 V', fontsize=7, ha='right')
    for x, s in ((10, 'esptool\nUnixTight'), (300, 'esptool\nClassic'), (600, 'monitor seriale\n(DTR=RTS=1)')):
        ax[1].annotate(s, (x, 3.45), fontsize=7)
    style(ax[1], 'ESP32', 'V'); ax[1].set_xlabel('ms'); ax[1].set_ylim(-0.2, 4.1); ax[1].legend(loc='right', fontsize=8)
    fig.tight_layout(); fig.savefig(f'grafici/{fn}.png', dpi=110); plt.close(fig)

# 02 buck
t, (v33, vp, il, sw) = load('out/02_buck_nominal.dat', 4)
fig, ax = plt.subplots(3, 1, figsize=(10, 7), sharex=True)
ax[0].plot(t*1e3, vp, label='+5V'); ax[0].plot(t*1e3, v33, label='+3V3'); style(ax[0], 'LM2596 — avvio e carichi ESP32 (60 / 250 / 500 mA)', 'V'); ax[0].legend(fontsize=8)
ax[1].plot(t*1e3, v33); ax[1].set_ylim(3.2, 3.35); style(ax[1], '+3V3 zoom', 'V')
ax[2].plot(t*1e3, il); ax[2].axhline(1.33, color='r', ls=':'); ax[2].text(24.5, 1.4, 'Isat L1 1.33 A', fontsize=7, ha='right', color='r')
style(ax[2], 'corrente in L1 (avvio con 5 V in 1 ms)', 'A'); ax[2].set_xlabel('ms')
fig.tight_layout(); fig.savefig('grafici/02_buck_nominal.png', dpi=110); plt.close(fig)

t, (v33, vp, il) = load('out/02b_buck_ledload_vsat.dat', 3)
fig, ax = plt.subplots(2, 1, figsize=(10, 5.5), sharex=True)
ax[0].plot(t*1e3, vp, label='+5V (LED da 0 a 3 A a 4-6 ms)'); ax[0].plot(t*1e3, v33, label='+3V3'); style(ax[0], 'Caso peggiore: LED a 3 A + Vsat reale + TX WiFi 500 mA (12-13 ms)', 'V'); ax[0].legend(fontsize=8)
ax[1].plot(t*1e3, v33); ax[1].axhline(3.0, color='r', ls=':'); ax[1].set_ylim(2.9, 3.45); style(ax[1], '+3V3 zoom (minimo ESP32 3.0 V)', 'V'); ax[1].set_xlabel('ms')
fig.tight_layout(); fig.savefig('grafici/02b_buck_ledload_vsat.png', dpi=110); plt.close(fig)

t, (v33, vp) = load('out/02c_buck_dropout.dat', 2)
fig, ax = plt.subplots(figsize=(10, 4))
ax.plot(t*1e3, vp, label='+5V (regolatore VIN)'); ax.plot(t*1e3, v33, label='+3V3 @ 500 mA'); ax.axhline(3.0, color='r', ls=':')
style(ax, 'Tensione minima in ingresso: 5.0 → 4.0 V a gradini, carico 500 mA, Vsat reale', 'V'); ax.set_xlabel('ms'); ax.legend(fontsize=8)
fig.tight_layout(); fig.savefig('grafici/02c_buck_dropout.png', dpi=110); plt.close(fig)

t, (v33, vp, il) = load('out/02d_buck_slowramp.dat', 3)
fig, ax = plt.subplots(2, 1, figsize=(10, 5), sharex=True)
ax[0].plot(t*1e3, vp, label='+5V'); ax[0].plot(t*1e3, v33, label='+3V3'); style(ax[0], 'Avvio con alimentatore reale (5 V in 10 ms)', 'V'); ax[0].legend(fontsize=8)
ax[1].plot(t*1e3, il); ax[1].axhline(1.33, color='r', ls=':'); style(ax[1], 'corrente in L1', 'A'); ax[1].set_xlabel('ms')
fig.tight_layout(); fig.savefig('grafici/02d_buck_slowramp.png', dpi=110); plt.close(fig)

# 03 power-on
for fn, tag in (('03_poweron', 'C4 100 nF'), ('03b_poweron_C4_1u', 'C4 1 µF')):
    t, (v33, ena, io0a, enb, io0b, enc, io0c) = load(f'out/{fn}.dat', 7)
    fig, ax = plt.subplots(figsize=(10, 4))
    ax.plot(t*1e3, v33, 'k', label='+3V3'); ax.plot(t*1e3, ena, label='EN, adattatore scollegato')
    ax.plot(t*1e3, enc, '--', label='EN, adattatore collegato a riposo'); ax.plot(t*1e3, io0c, ':', label='IO0, adattatore collegato')
    ax.axhline(2.475, color='gray', ls=':', lw=1)
    style(ax, f'Accensione — {tag}', 'V'); ax.set_xlabel('ms'); ax.legend(fontsize=8)
    fig.tight_layout(); fig.savefig(f'grafici/{fn}.png', dpi=110); plt.close(fig)

# 04 status LED
a = np.loadtxt('out/04_status_led.dat')
fig, ax = plt.subplots(figsize=(8, 3.5))
ax.plot(a[:, 0], a[:, 1]*1e3, label='LED rosso'); ax.plot(a[:, 0], a[:, 3]*1e3, label='LED bianco/blu')
style(ax, 'LED di stato D1 con R0 470 Ω', 'mA'); ax.set_xlabel('tensione +5V (V)'); ax.legend(fontsize=8)
fig.tight_layout(); fig.savefig('grafici/04_status_led.png', dpi=110); plt.close(fig)

# 05 data line
t, (g, a_, b_, c_, d_) = load('out/05_dataline.dat', 5)
fig, ax = plt.subplots(figsize=(10, 4))
ax.plot(t*1e6, g, 'k', lw=1, label='GPIO13')
for y, l in ((a_, 'R5 470 Ω, cavo 0.3 m'), (b_, 'R5 470 Ω, cavo 0.6 m'), (c_, 'R5 100 Ω, cavo 0.3 m'), (d_, 'R5 100 Ω, cavo 0.6 m')):
    ax.plot(t*1e6, y, label=l)
ax.axhline(2.5, color='gray', ls=':', lw=1)
style(ax, 'Linea dati alle foglie (9 in parallelo), bit 0 1 0 1 1 0 a 800 kHz', 'V'); ax.set_xlabel('µs'); ax.legend(fontsize=8, loc='upper right')
fig.tight_layout(); fig.savefig('grafici/05_dataline.png', dpi=110); plt.close(fig)
print('ok')

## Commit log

2026-04-22 chore: initialize repository structure
    - Add docs/ (hardware, ios-app, 3d-printing, assembly, hardware-reviews)
    - Add CHANGELOG, CONTRIBUTING, LICENSE-NOTICES, .gitattributes
    - Add per-folder READMEs for PCB/ and 3D/
    - Update README with badges, Liquid Glass iOS section, status table
    - Update CONTEXT.md and .gitignore (WLED-iOS/ ignored, fp-info-cache pattern, .step binary)
    - Remove KiCad cruft: fp-info-cache ×4, -backups/ ×3, duplicate zips, DS_Store, analysis JSON
    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
    [BaseChipOnly-B_Cu.gbr, BaseChipOnly-B_Mask.gbr, BaseChipOnly-B_Paste.gbr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]
2026-08-16 chore: update 3D models and PCB layout
    Replace vaso/tappo STLs with new revisions (BaseVaso, Foglia, TasselloFissaggioPCB, VasoGiusto); minor kicad_pcb update.
    [BaseChipOnly.kicad_pcb, BaseVaso.stl, Foglia.stl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]
2026-08-16 docs: sync READMEs with renamed/added 3D model files
    VASO_Corpo/VASO-tappo were replaced by VasoGiusto/BaseVaso/Foglia/TasselloFissaggioPCB; update file tables and assembly steps to match.
2026-08-18 docs: mark VasoGiusto body as WIP
    Print revealed top/bottom attach points fail and MB engraving needs rework; body is being redesigned externally.
2026-09-24 3D: modular vase redesign — organize STL exports, update docs
    Vase redesigned in Fusion 360 as a modular assembly (base + lid +
    trunk + 3 branches + leaves) with bayonet/snap-fit joints, replacing
    the single-piece VasoGiusto body. Adds Fusion source (3D/Vaso/) and
    print-ready STLs (3D/STL_stampa/), plus assembly animation renders.
    - Remove superseded single-piece files: VasoGiusto.stl, BaseVaso.stl,
    old Foglia.stl/Foglia.3mf
    - Remove ~400MB of intermediate animation frame dumps and an earlier
    animation take, superseded by the current renders; gitignore future
    frame dumps
    - Update README, 3D/README.md, docs/3d-printing.md, docs/assembly.md,
    CHANGELOG.md for the modular design and e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
    [Base.step, Base.stl, BaseVaso.stl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]
2026-09-24 docs: redesign README hero layout, fix email, add website link
    Restructure README with a centered hero (full-assembly GIF up top),
    a 3-column feature grid, and a cleaner side-by-side assembly gallery
    instead of the cramped table layout. Fix contact email typo
    (barleramarco2 -> barleramarco05) across README, LICENSE-NOTICES,
    CONTRIBUTING, and add marcobarlera.com.
2026-09-24 docs: document PCB compatibility of the 3D files (BaseChipOnly only)
    Coperchio.stl (the lid) carries the PCB mounting points, and
    TasselloFissaggioPCB.stl mounts the board inside it. Both are
    designed to match the BaseChipOnly variant's outline/holes. Using
    BaseDevKit or BaseUSB-C requires redesigning the lid's mounting
    points first — call this out in 3D/README.md, docs/3d-printing.md,
    and docs/assembly.md so it isn't assumed to fit any PCB variant.
2026-09-24 docs: fix PCB mount location (base, not lid)
    The PCB mounts inside Base.stl via TasselloFissaggioPCB.stl, not the
    lid (Coperchio.stl) — correcting the previous doc pass.
2026-09-24 build: wire WLED-iOS in as a proper git submodule
    Replace the standalone WLED-iOS/ clone with a git submodule tracking
    ZonatedCord/WLED-iOS's liquid-glass-redesign branch, so the app's
    commit is pinned and `git clone --recurse-submodules` pulls it in
    automatically instead of relying on a manual second clone.
2026-09-30 feat(pcb): BaseChipOnly rev with all bring-up fixes and new layout Schematic: D1/D2 polarity, cross-coupled DTR/RTS auto-reset, BOOT/RESET buttons, L1 SRN6045TA-101M, polyfuse MF-LSMF400/12X (4A), SM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
    [BaseChipOnly-BOM.csv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]
2026-09-30 docs: update BaseChipOnly docs; drop stale Gerber copy
    - README, hardware.md, PCB/README: rev 1.03 (fabricated) vs next rev
    in "BaseChipOnly copia MCP/" (all fixes, not yet fabricated)
    - assembly.md: flashing via J3 + BOOT/RESET, WLED GPIO13 / 15 LEDs,
    power budget for 9 leaves (135 LEDs): 5 V 4 A PSU + WLED limiter
    3000 mA (was "5 V 2 A")
    - base-chiponly-fixes.md: workarounds apply to rev 1.03 only
    - CHANGELOG: BaseChipOnly next rev, docs fixes
    - Untrack the stale copy of the rev 1.03 Gerbers and the old DRC
    report committed by mistake in 770f189 (now in .gitignore)
    - Add the scripts that generate the new PCB (fixpcb, relayout, build)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
    [BaseChipOnly-B_Cu.gbr, BaseChipOnly-B_Mask.gbr, BaseChipOnly-B_Paste.gbr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]
2026-10-01 feat(pcb): BaseChipOnly HW Rev 2.0 - simulations, roomier layout, rename
    - Rename "PCB/BaseChipOnly copia MCP/" to "PCB/BaseChipOnly_rev2/";
    silkscreen now reads HW Rev 2.0
    - New README for the folder: limitation (verified on paper only, not
    fabricated or tested on hardware), tests performed, changes vs rev 1.03
    - ngspice simulations of every analog block (auto-reset, power-on,
    LM2596 nominal/worst case/dropout/start-up, status LED, LED data line)
    with plots; TI LM2596 model fetched by script, not stored
    - From the simulations: C4 100nF -> 1uF, R5 470R -> 100R,
    auto-reset transistors specified as MMBT3904
    - COUT2 MPN: Kyocera AVX TPSC227M006R0100
    - Layout: regulator block spaced ~1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
    [BaseChipOnly-BOM.csv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]
2026-10-16 docs: record vase/base/lid/leaves/branch 1 prints, add Rami.3mf print plate
2026-10-16 docs: clarify vase/lid print orientation (upside down = 180°)
2026-10-16 docs: note branch numbers are inside the mounting boss
2026-10-16 chore(pcb): keep only simulation results, drop ngspice decks and scripts
2026-10-16 3D: update Rami.3mf print plate
2026-10-16 docs: all 3 branches printed; note hard-to-remove inner supports
2026-10-18 3D: fix Base.stl cable passage, remove small piece blocking the slit
    Re-exported from Fusion after removing the piece that blocked the cable
    passage, so the cable can also run perpendicular to the slit.
2026-10-18 3D: final Base.stl (cable passage open from the bottom), add wiring tips
    Re-exported from Fusion v34. Docs: recommend thin wires in the branches
    and Wago-style connectors to join the three conductors.
2026-10-18 3D: add TasselloFissaggioPCB.stl to the print-ready STLs
2026-10-18 3D: keep a single TasselloFissaggioPCB.stl in STL_stampa and list it in the docs
2026-10-19 3D: align Vaso/Coperchio.stl with the latest STL
2026-10-19 chore(pcb): untrack one-shot rev2 migration scripts
    fixpcb_2026-09-30.py, relayout.py and build.sh turned the rev 1.03 board
    into the rev 2.0 one; their inputs live only in the ignored backups folder,
    so they cannot be re-run from the repo. Local copies are kept.
2026-10-19 docs: wiring tips - long wires, sizing method, colour code
2026-10-19 docs: clarify wire colours are only a convention
2026-10-19 docs: prototype built and working; leaves to be reprinted
2026-10-21 docs: recommend solder paste stencils, leaf top stencil reusable for the bottom
2026-10-23 docs: add 3D renders of BaseChipOnly Rev 1.03 and Rev 2.0 to the README
    Rendered with kicad-cli pcb render (KiCad 9), top and bottom. PCB/README.md
    documents the command to regenerate them.
2026-10-23 docs: complete PCB renders via a script that adds missing 3D models to temp copies
    PCB/render/make_renders.py adds the ESP32 module, barrel jack and, for
    Rev 2.0, hand-made polyfuse and PTS810 button models to temporary copies of
    the boards, then renders top/bottom with kicad-cli. The board files are not
    modified.
2026-10-23 docs: leaf LED D8 is soldered vertically, half on top and half on bottom
2026-10-23 docs: add leaf board (Foglia) top and bottom renders
2026-10-23 docs: align versions (KiCad 9, Xcode 26, iOS target) and remove placeholders
    KiCad projects are saved with 9.0; the iOS app deployment target is 16.0
    (Liquid Glass design targets iOS 26, project saved with Xcode 26.2). Drop
    references to notes that are not in the repo.
2026-10-26 docs: add prototype, electronics and earlier-version photos to the README

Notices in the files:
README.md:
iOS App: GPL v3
